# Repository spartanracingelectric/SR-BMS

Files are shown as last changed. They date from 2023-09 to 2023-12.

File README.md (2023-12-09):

# Spartan Racing BMS R&D Repository
A senior project with a goal to produce an in-house BMS using the LTC6813 to support a 600V pack, as well as analysis software to view cell data and configure the BMS.<br/>
<br/>

## Project Demonstration
YouTube Video of Project Demo (https://www.youtube.com/watch?v=ieQdnhzClfs)

## Project Folder Structure
- `altium/` : Altium Designer project files for the custom BMS master and slave PCB (schematic & layout)
- `doc/` : Supplementary documentation, mostly hardware-related (like datasheets)
- `examples/` : Firmware examples for the BMS master, various programs.
	- The primary example that was utilized was `stm32f105_isospi`
- `gui/` : GUI Analysis Software for the host computer , to visualize battery cell data and communicate with the BMS master PCBA.
- `media/` : Various photos and such

## Environment Setup
### Version Control
1. Install git ([Windows](https://git-scm.com/downloads))
2. Clone this repo into any reachable folder using, in a command line of your choice (WSL Ubuntu, PowerShell, Terminal, etc), `git clone https://github.com/spartanracingelectric/SR-BMS.git`
    1. Change your branch if necessary by using `git checkout <BRANCH_NAME>`

### Altium Designer PCB Design Setup
Simple, just open either the master or slave `.PrjPcb` files in Altium!

### Firmware Setup
1. Install STM32CubeIDE and STM32CubeProgrammer.
2. In STM32CubeIDE, import the projects from `examples/`.
3. In STM32CubeIDE, click the "build" hammer on the toolbar to compile/build one of the programs in `examples/`.
4. In STM32CubeProgrammer, flash the `.elf` binary generated in the specific example project's `Debug/` to the BMS master PCBA over ST-Link or USB.
5. Note: STM32CubeMX to make any initialization-level configuration changes for the microcontroller.

### GUI Setup
1. cd gui/bms_app
	- install necessary react scripts using 'npm install react-scripts' 
2. Backend and frontend must be run concurrently 
	- frontend: open terminal in bms_app folder use: 'npm start' 
	- backend: open terminal in serialcomm folder 'npm run dev' 
	- backend deals w/ serial communication. Ensure that the correct COM port is defined in server.js!
	- to view the backend use the url: "http://localhost:8000/graphdata" 
<br/>

## SR BMS R&D Senior Project Team
_Vincent Saw_, Ex-Software Lead for Spartan Racing, Firmware & Hardware & Integration<br/>
_Vincent Pham_, Project Member, Firmware & Hardware<br/>
_Josh Samoy_, Project Member, Firmware & Software<br/>
_Abegail Palad_, Project Member, Firmware & Software<br/>
<br/>

## Links
[Primary Repo for BMS Senior Project](https://github.com/spartanracingelectric/SR-BMS)<br/>
[Old GUI Analysis Software Repo](https://github.com/Sensei-Josh/Senior_project_GUI)<br/>
[Spartan Racing Website](https://www.sjsuformulasae.com/)<br/>

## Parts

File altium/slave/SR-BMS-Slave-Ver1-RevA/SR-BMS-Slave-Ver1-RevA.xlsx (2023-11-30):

Line # | Name | Description | Designator | Quantity | Manufacturer 1 | Manufacturer Part Number 1 | Manufacturer Lifecycle 1 | Supplier 1 | Supplier Part Number 1 | Supplier Unit Price 1 | Supplier Subtotal 1
 | 885382207009 | Multilayer Ceramic Chip Capacitor WCAP-CSST Series 0805 10000pF X7R0805103K100DFCT1S000 | C0, C1, C2, C3, C4, C5, C6, C7, C8, C9, C10, C11, C12, C13, C14, C15, C16, C17, C18, C19, C20, C21, C22, C23, C25, C26, C27, C28, C29, C30, C31, C32, C33, C34, C35, C36, C53, C54, C55, C56 | 40
 | Capacitor | Capacitor | C37, C38, C39, C40, C41, C42, C43, C44, C45, C46, C47 | 11
 | Capacitor | Capacitor | C48, C49, C50, C51, C52 | 5
 | MFU0603FF00500P500 | Fuse | F1, F2, F3, F4, F5, F6, F7, F8, F9, F10, F11, F12, F13, F14, F15, F16, F17, F18 | 18
 | BLM18PG330SN1D | Ferrite Bead | FB1 | 1
 | 15-91-2025 | CONN HEADER SMD R/A 2POS 2.54MM | J1, J2 | 2 | Molex | 15-91-2025 | Volume Production | Farnell | 3862877 | 3.08 | 6.16
 | 70553-0044 | Connector | J3 | 1
 | 70555-0018 | Connector | J4 | 1
 | LS_L29K-G1H2-1 | LED | LED1, LED2, LED3, LED4, LED5, LED6, LED7, LED8, LED9, LED10, LED11, LED12, LED13, LED14, LED15, LED16, LED17, LED18 | 18
 | BSS308PE | P-Channel OptiMOS P3 Small-Signal-Transistor, -30 V VDS, -2 A ID, -55 to 150 degC, PG-SOT23, Reel, Green | Q1, Q2, Q3, Q4, Q5, Q6, Q7, Q8, Q9, Q10, Q11, Q12, Q13, Q14, Q15, Q16, Q17, Q18 | 18 | Infineon | BSS308PE | Volume Production | Digi-Key | BSS308PEH6327XTSA1CT-ND | 0.358 | 6.44
 | NSV1C201MZ4T1G | Transistor | Q19 | 1
 | Resistor | Resistor | R1, R2, R3, R4, R5, R6, R7, R8, R9, R10, R12, R13, R14, R15, R16, R17, R18, R19, R20, R26, R27, R28, R29, R30, R31, R32, R33, R34, R36, R37, R38, R39, R43, R44, R45, R47, R48, R50, R51, R52, R53, R54, R58, R59, R60, R61, R62, R63, R66, R67, R68, R69, R70, R71 | 54
 | Resistor | Resistor | R11, R21, R22, R23, R24, R25, R35, R40, R41, R42, R46, R55, R56, R57, R64, R65, R72, R73 | 18
 | Resistor | Resistor | R49, R74 | 2
 | Resistor | Resistor | R75, R76, R77, R78, R79, R80, R81, R82, R83 | 9
 | Resistor | Resistor | R84, R87, R88, R89, R90, R91 | 6
 | Resistor | Resistor | R85 | 1
 | Resistor | Resistor | R86 | 1
 | Resistor | Resistor | R92 | 1
 | Resistor | Resistor | R94, R95, R96, R97 | 4
 | SM91502ALE | BMS XFORMER 1-CH 1000V AECQ +125 | T1, T2 | 2 | Bourns | SM91502ALE | Volume Production | Newark | 95AC3538 | 2.81 | 5.62
 | LTC6813HLWE-1#3ZZPBF | 18 CHANNEL MULTICELL BATTERY STA | U1 | 1 | Analog Devices / Linear Technology | LTC6813HLWE-1#3ZZPBF | Unknown
 | PDZ7.5B,115 | Zener Diode | Z1, Z2, Z3, Z4, Z5, Z6, Z7, Z8, Z9, Z10, Z11, Z12, Z13, Z14, Z15, Z16, Z17, Z18 | 18

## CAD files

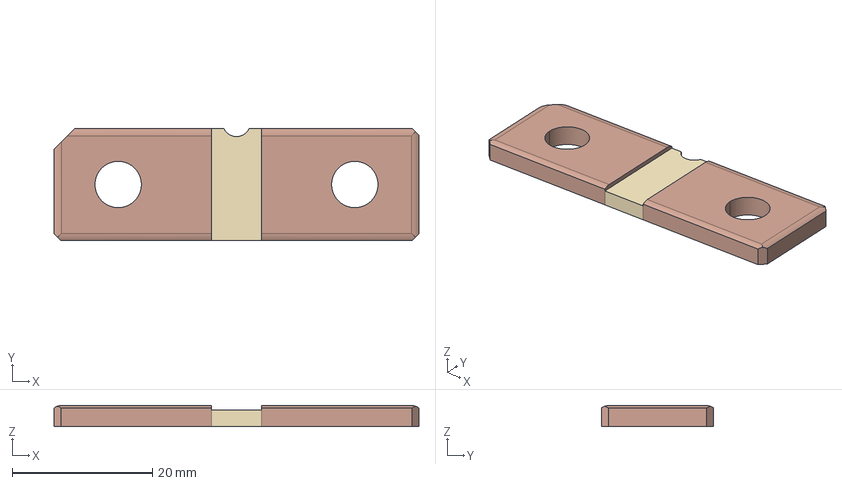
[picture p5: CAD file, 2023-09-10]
altium/master/stm32f105/SR-BMS-Master-Ver1-RevB_stm32f105/WSBS5216L1000KK.stp
52.0 x 16.0 x 3.00 mm

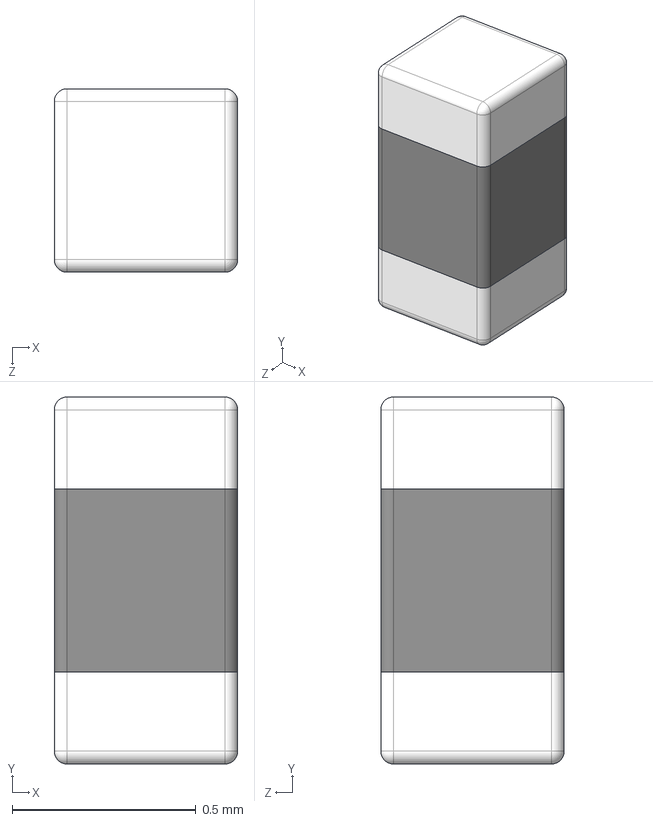
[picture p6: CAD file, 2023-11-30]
altium/slave/SR-BMS-Slave-Ver1-RevA/dependencies/LIB_BLM15PX600BH1D/BLM15PX600BH1D/3D/BLM15PX600BH1D.stp
0.5 x 1.00 x 0.5 mm

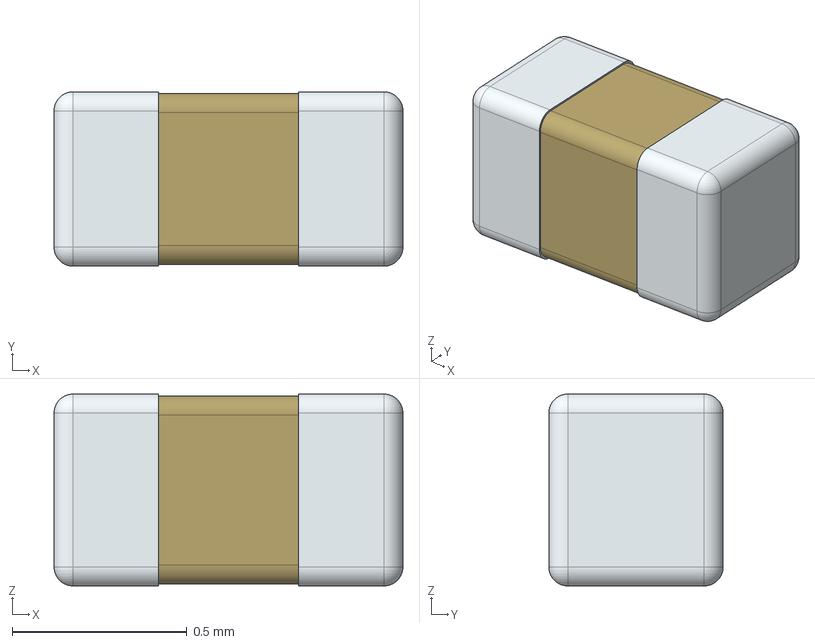
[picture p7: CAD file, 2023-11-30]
altium/slave/SR-BMS-Slave-Ver1-RevA/dependencies/LIB_C0402C103K1RACAUTO/C0402C103K1RACAUTO/3D/C0402C103K1RACAUTO.stp
1.00 x 0.5 x 0.55 mm

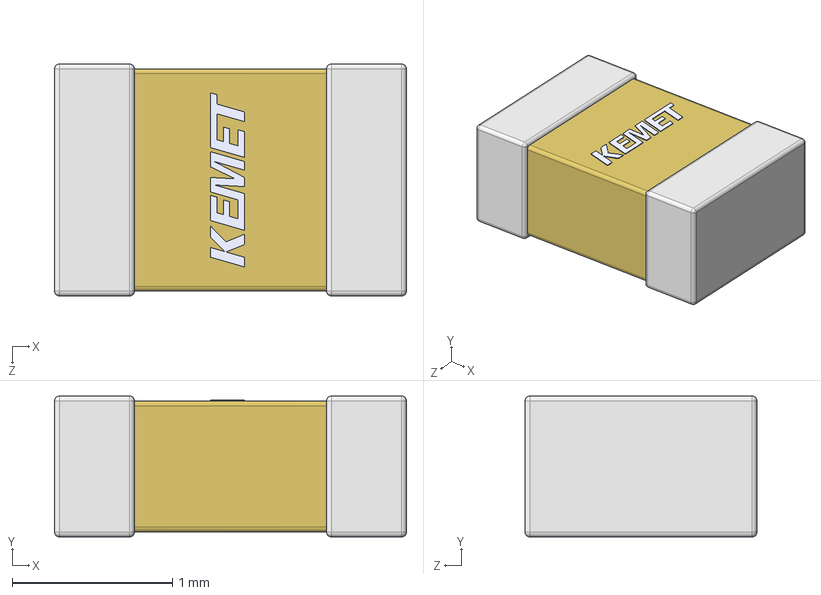
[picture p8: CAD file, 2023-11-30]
altium/slave/SR-BMS-Slave-Ver1-RevA/dependencies/LIB_C0805C109B3GACTU/C0805C109B3GACTU/3D/C0805C109B3GACTU.stp
2.20 x 0.88 x 1.45 mm

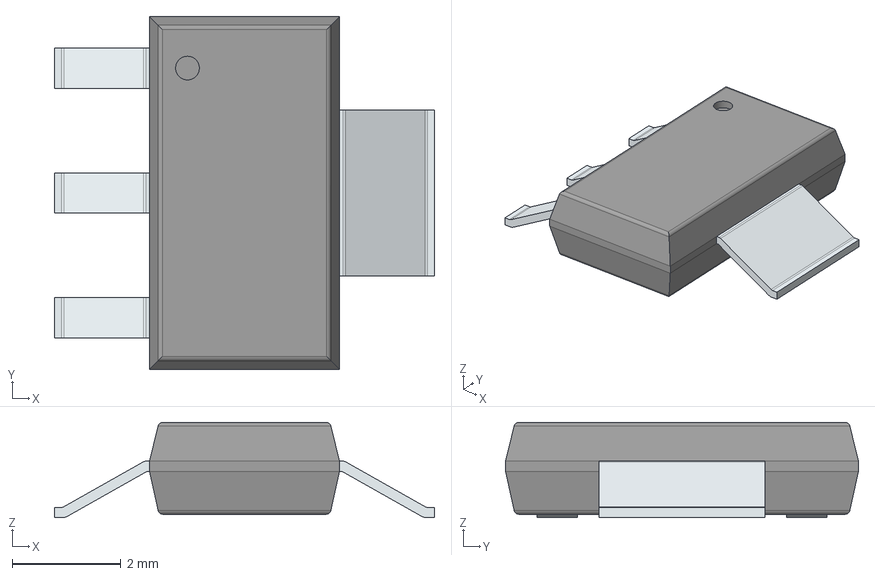
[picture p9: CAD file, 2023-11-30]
altium/slave/SR-BMS-Slave-Ver1-RevA/dependencies/LIB_NSV1C201MZ4T1G/NSV1C201MZ4T1G/3D/NSV1C201MZ4T1G.stp
7.00 x 6.50 x 1.75 mm
PinsArrayL
FilletPinR

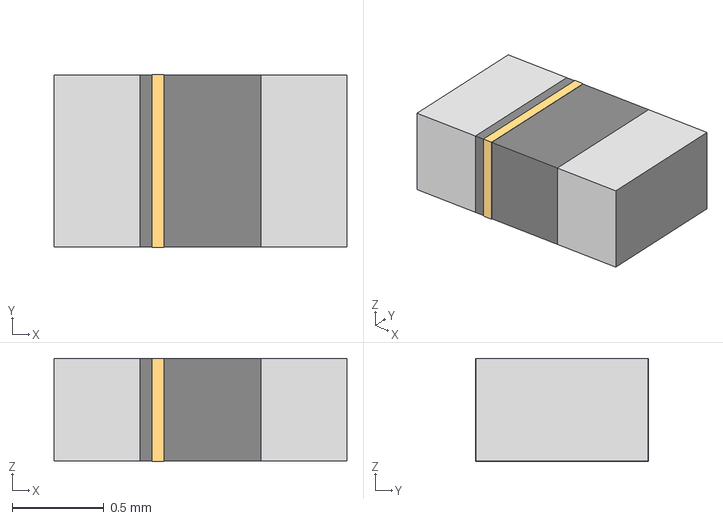
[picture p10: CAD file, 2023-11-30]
altium/slave/SR-BMS-Slave-Ver1-RevA/dependencies/ul_MFU0603FF00500P500/AltiumDesigner/FUS_VISHAY_MFU0603_VIS.step
1.60 x 0.944 x 0.564 mm

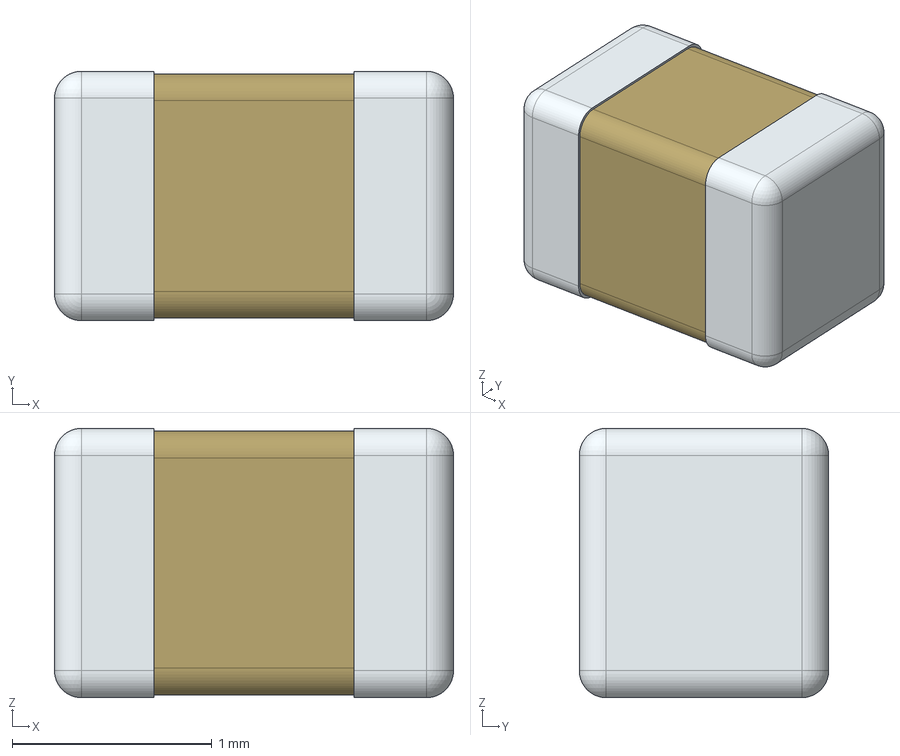
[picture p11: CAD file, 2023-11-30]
altium/slave/SR-BMS-Slave-Ver1-RevA/dependencies/LIB_885382207009/885382207009/3D/885382207009.stp
2.00 x 1.25 x 1.35 mm

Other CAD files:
altium/slave/SR-BMS-Slave-Ver1-RevA/dependencies/LIB_885382207009/885382207009/Allegro/capc2012x135n.psm
altium/slave/SR-BMS-Slave-Ver1-RevA/dependencies/LIB_885382207009/885382207009/DEHDL/885382207009/chips/chips.prt
altium/slave/SR-BMS-Slave-Ver1-RevA/dependencies/LIB_BLM15PX600BH1D/BLM15PX600BH1D/Allegro/nfz15sg152sn10b.psm
altium/slave/SR-BMS-Slave-Ver1-RevA/dependencies/LIB_BLM15PX600BH1D/BLM15PX600BH1D/DEHDL/blm15px600bh1d/chips/chips.prt
altium/slave/SR-BMS-Slave-Ver1-RevA/dependencies/LIB_C0402C103K1RACAUTO/C0402C103K1RACAUTO/Allegro/capc1005x55n.psm
altium/slave/SR-BMS-Slave-Ver1-RevA/dependencies/LIB_C0402C103K1RACAUTO/C0402C103K1RACAUTO/DEHDL/c0402c103k1racauto/chips/chips.prt
altium/slave/SR-BMS-Slave-Ver1-RevA/dependencies/LIB_C0805C109B3GACTU/C0805C109B3GACTU/Allegro/c0805.psm
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

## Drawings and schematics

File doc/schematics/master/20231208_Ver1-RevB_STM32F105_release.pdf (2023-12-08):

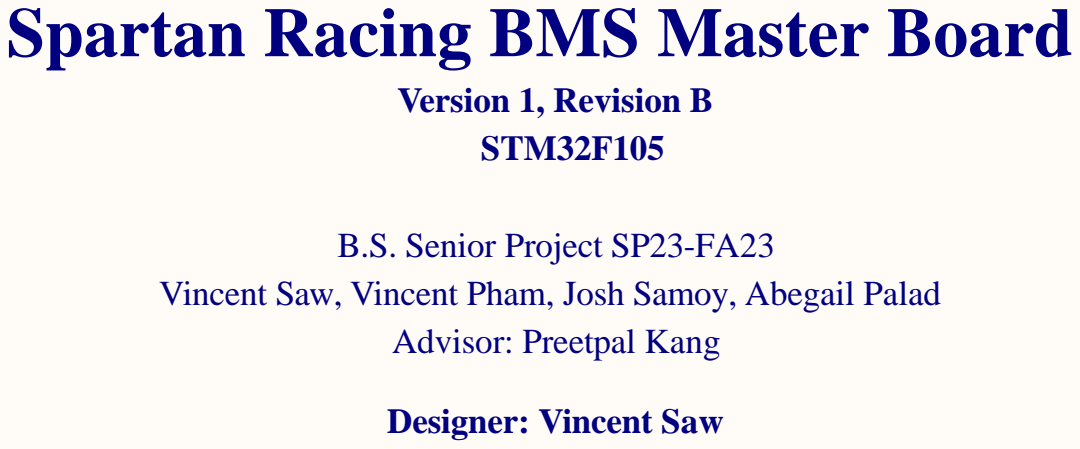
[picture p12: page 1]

Spartan Racing BMS Master Board

Vincent Saw, Vincent Pham, Josh Samoy, Abegail Palad

Title
BMS Master Cover Sheet

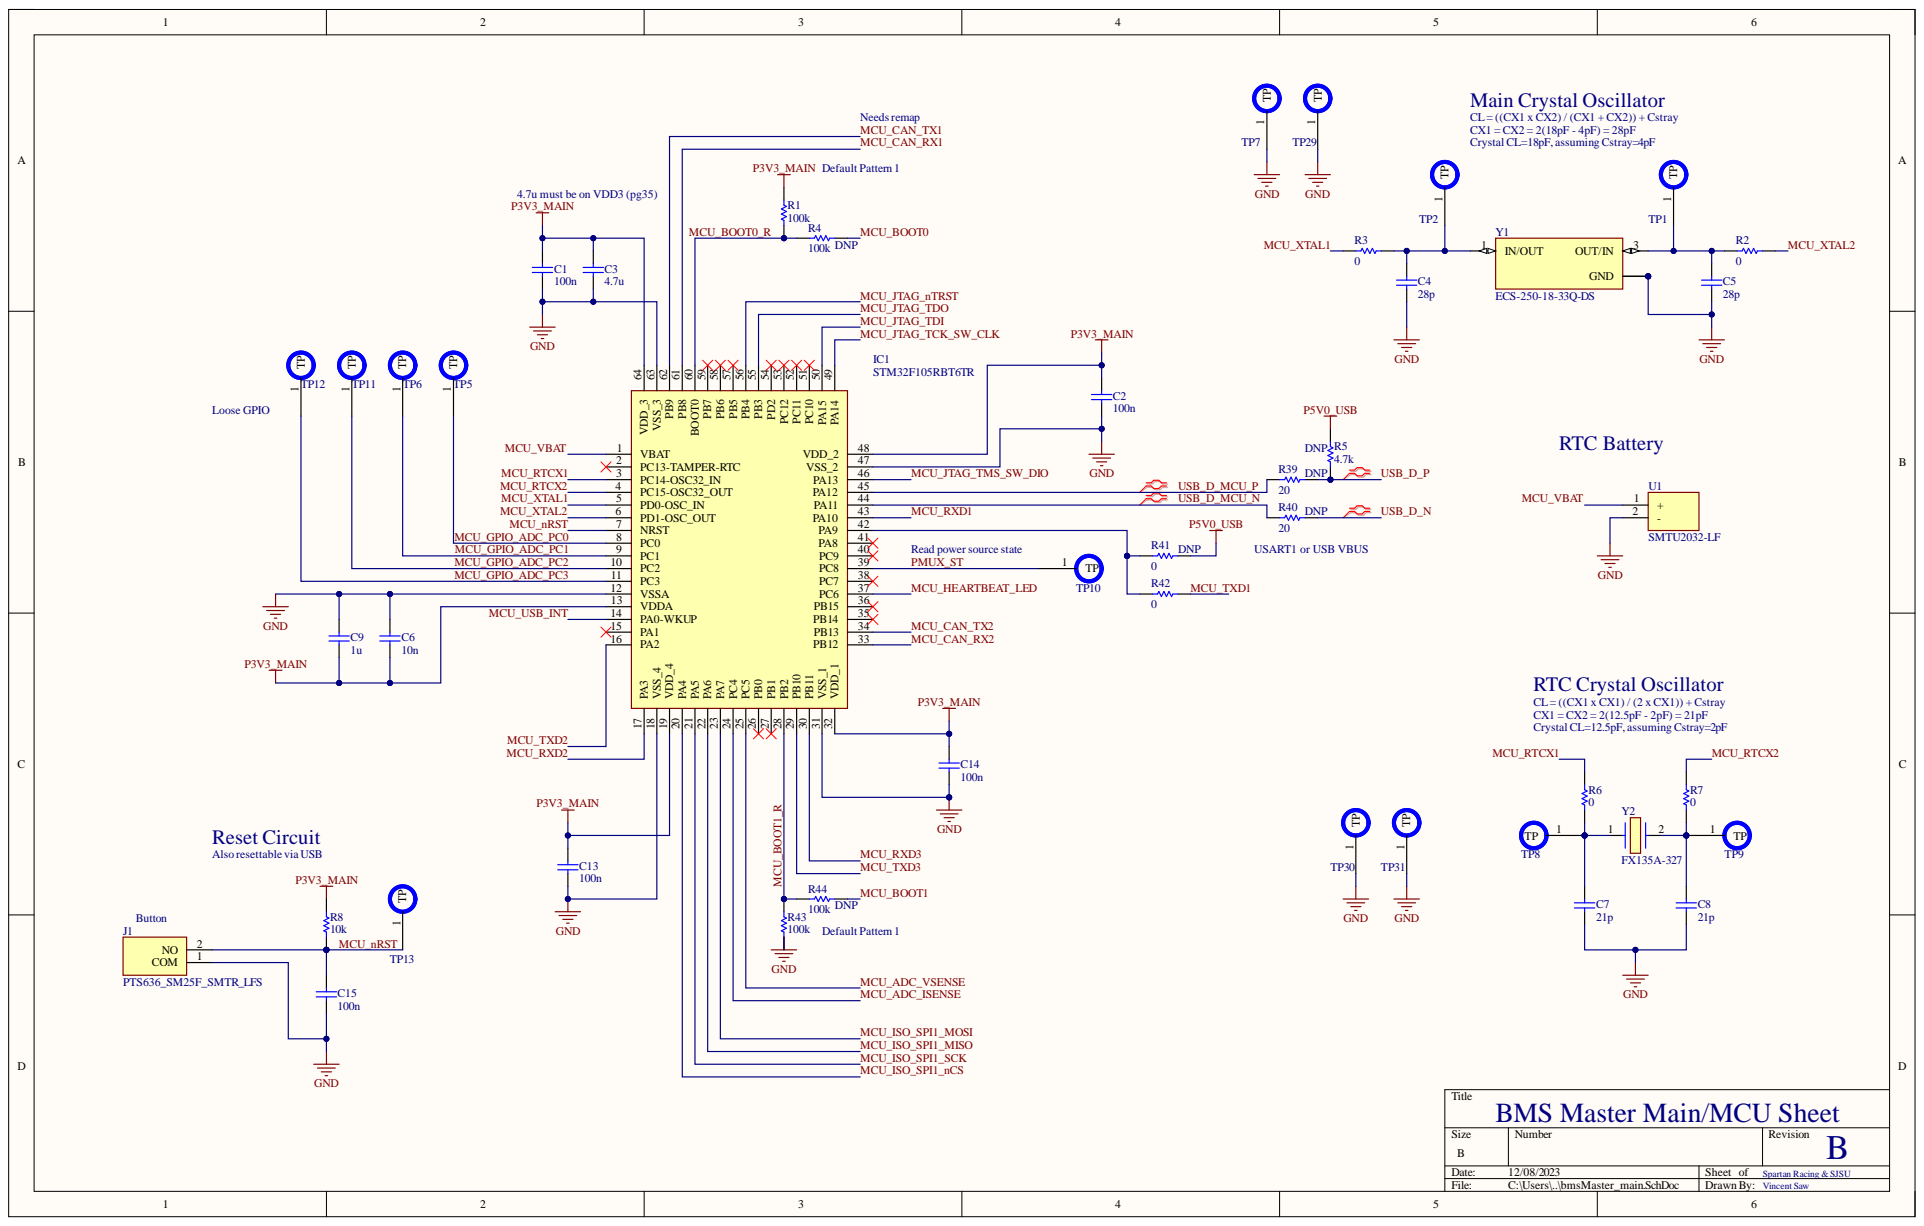
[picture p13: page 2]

Main Crystal Oscillator

PC14-OSC32_IN 3 | MCU_JTAG_TMS_SW_DIO GND
PC15-OSC32_OUT 4 | | USB_D_MCU_P
PD0-OSC_IN 5 | USB_D_MCU_N | + 1

RTC Crystal Oscillator CL= ((CX1 x CX1) / (2 x CX1)) + Cstray

Reset Circuit
Also resettable via USB

Title
BMS Master Main/MCU Sheet

Size B | Number | Revision B

Date: 12/08/2023 | Sheet of Spartan Racing & SJSU
File: C:\Users\..\bmsMaster_main.SchDoc | Drawn By: Vincent Saw

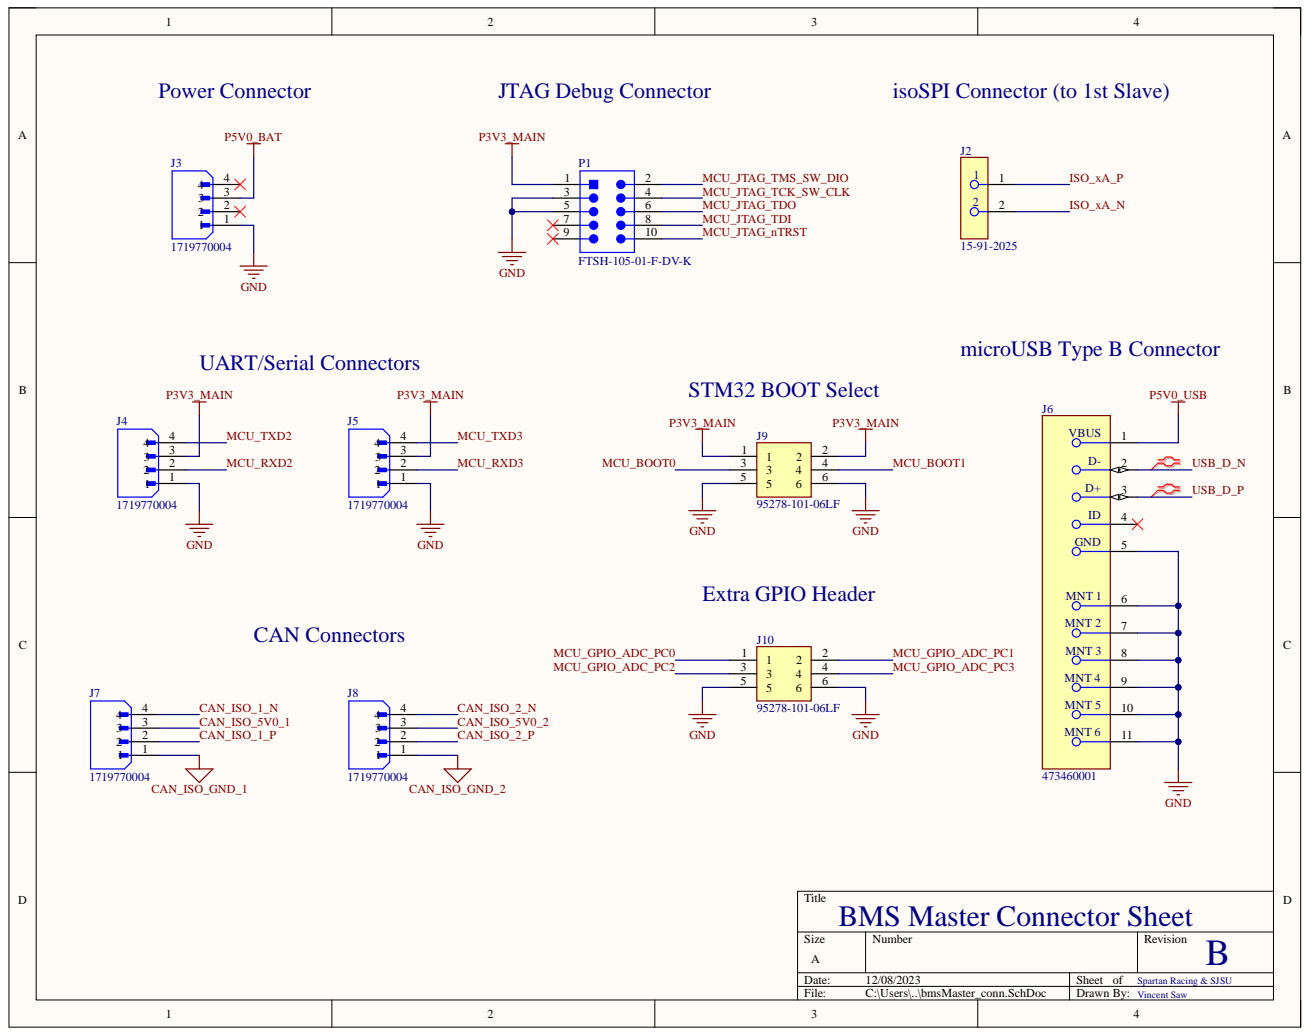
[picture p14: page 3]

Title
BMS Master Connector Sheet

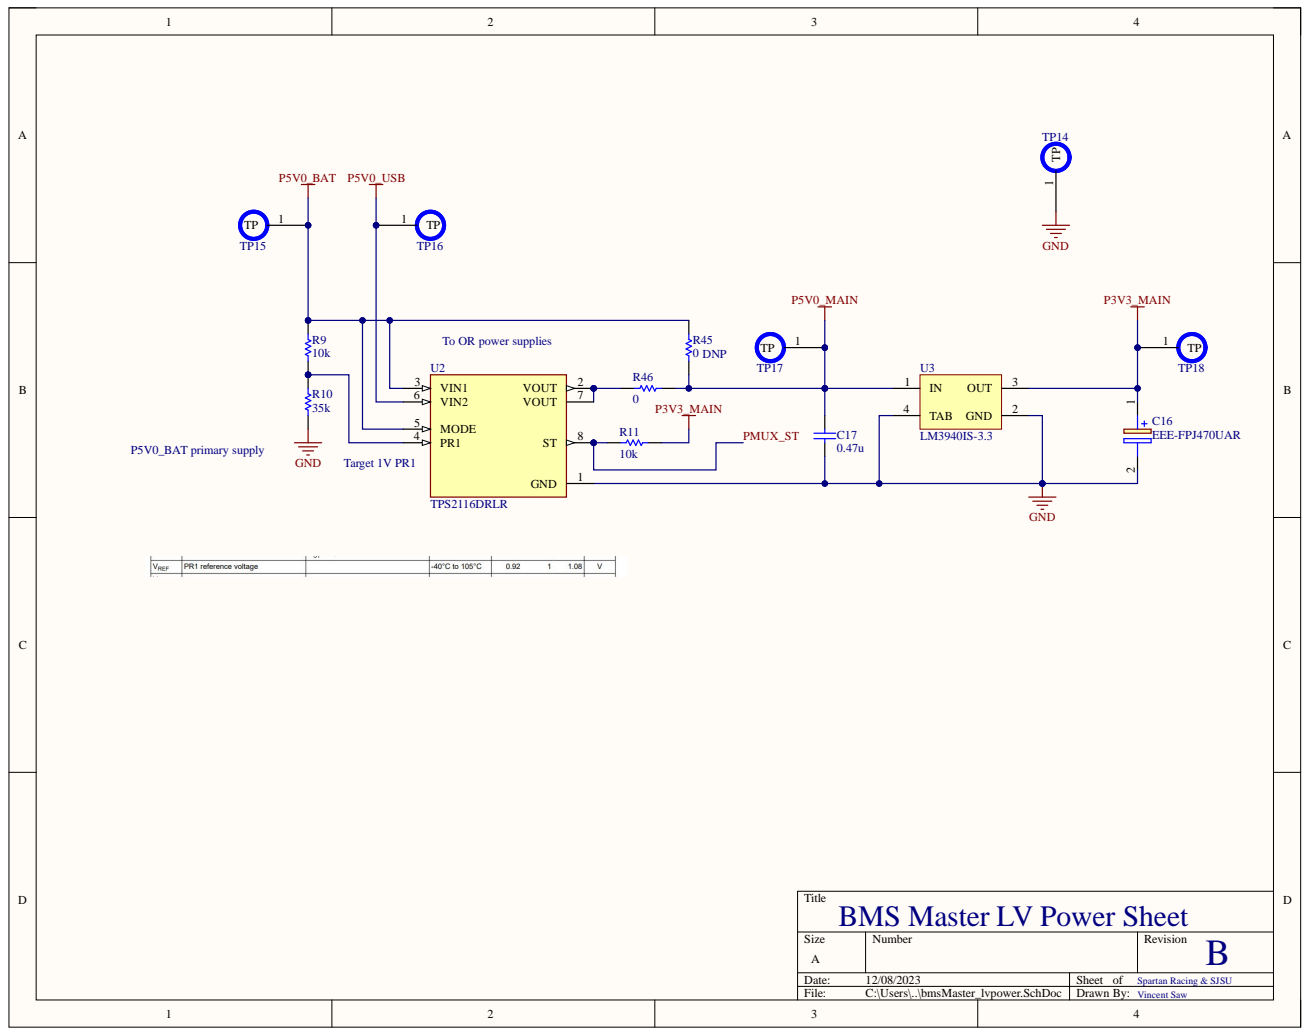
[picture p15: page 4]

To OR power supplies

Title
BMS Master LV Power Sheet

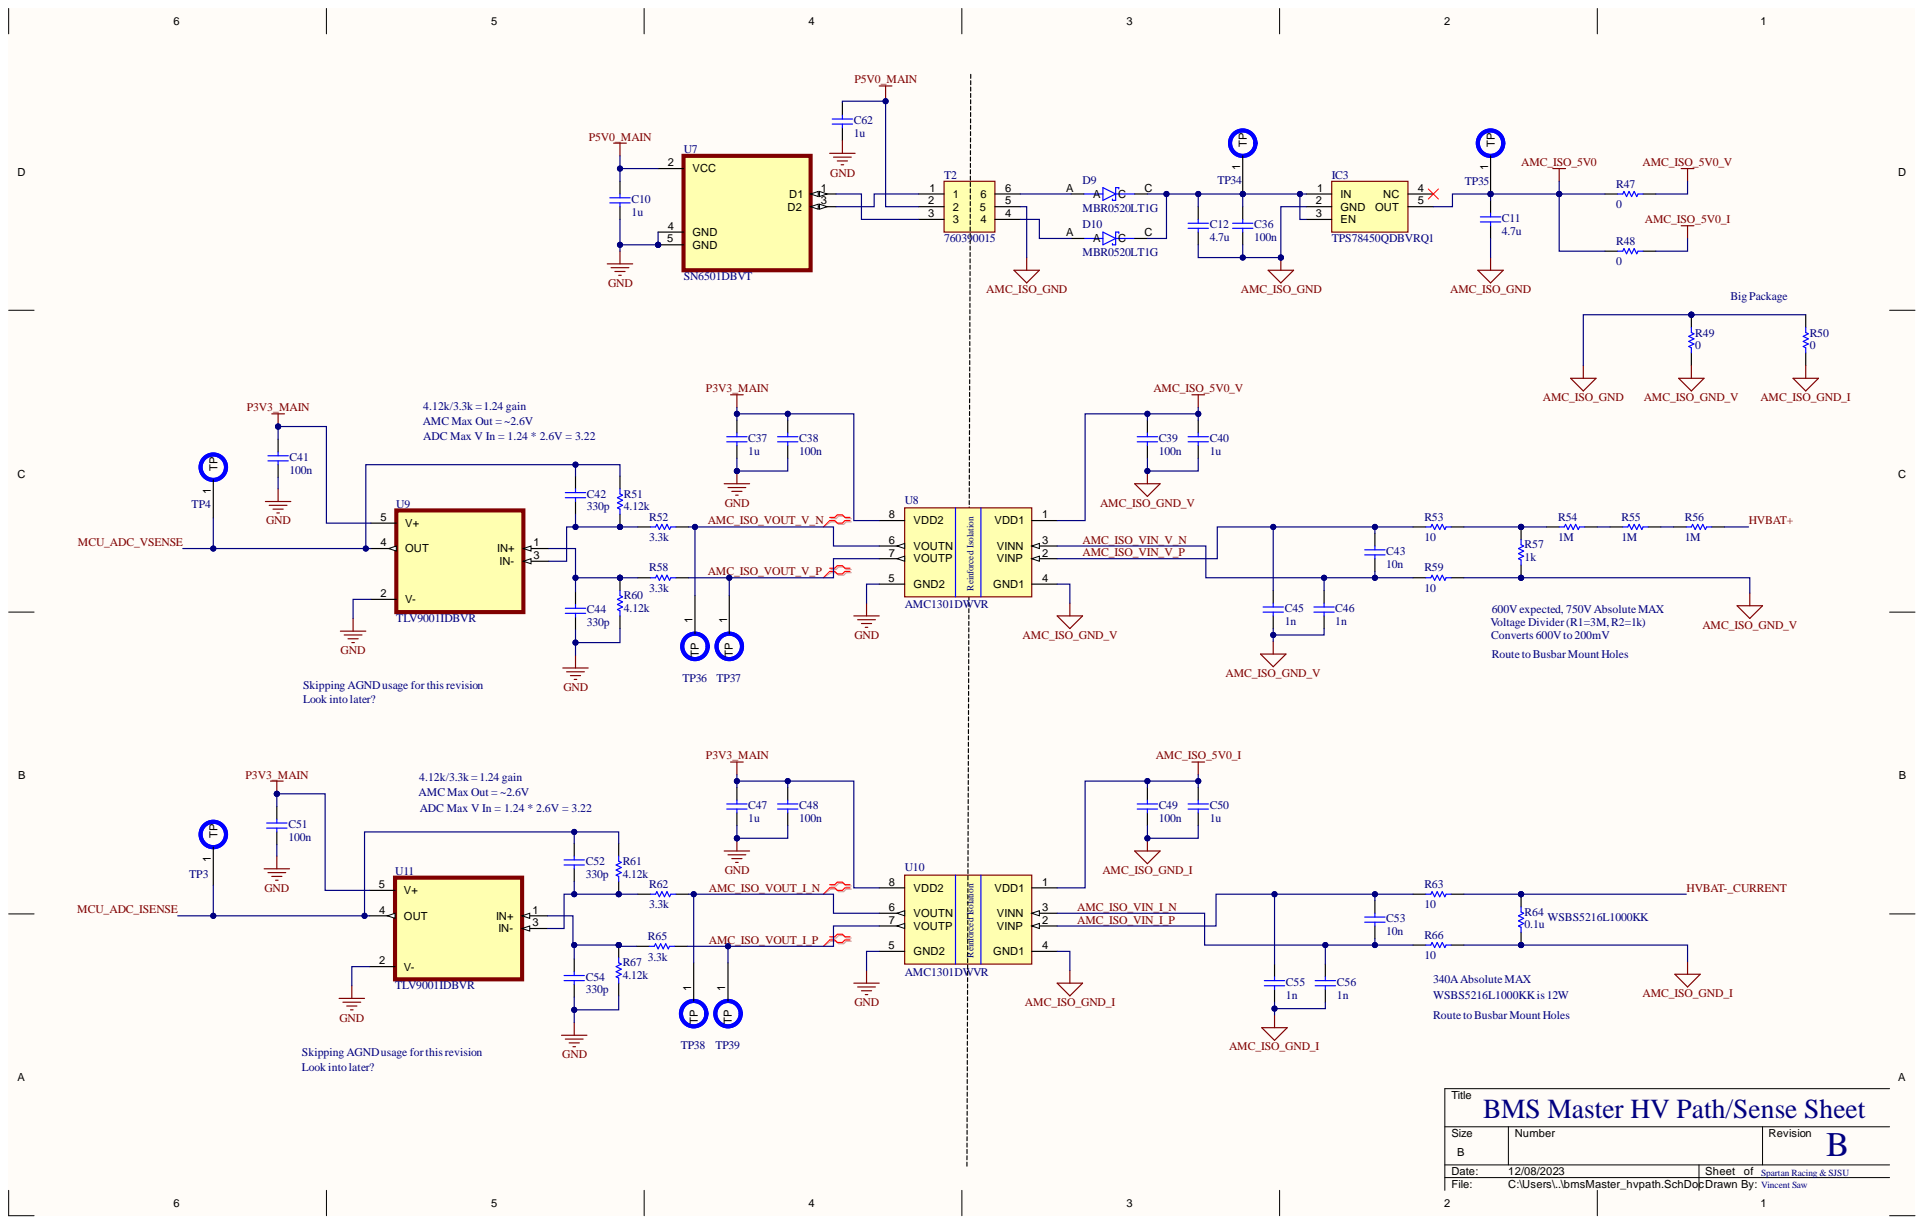
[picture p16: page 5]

600V expected, 750V Absolute MAX
Voltage Divider(R1=3M, R2=1k)
Converts 600V to 200mV
Route to Busbar Mount Holes

WSBS5216L1000KKis 12W

Title
BMS Master HV Path/Sense Sheet

Size B | Number | Revision B

Date: 12/08/2023 | Sheet of Spartan Racing & SJSU
File: C:\Users\..\bmsMaster_hvpath.SchDocDrawn By: | Vincent Saw

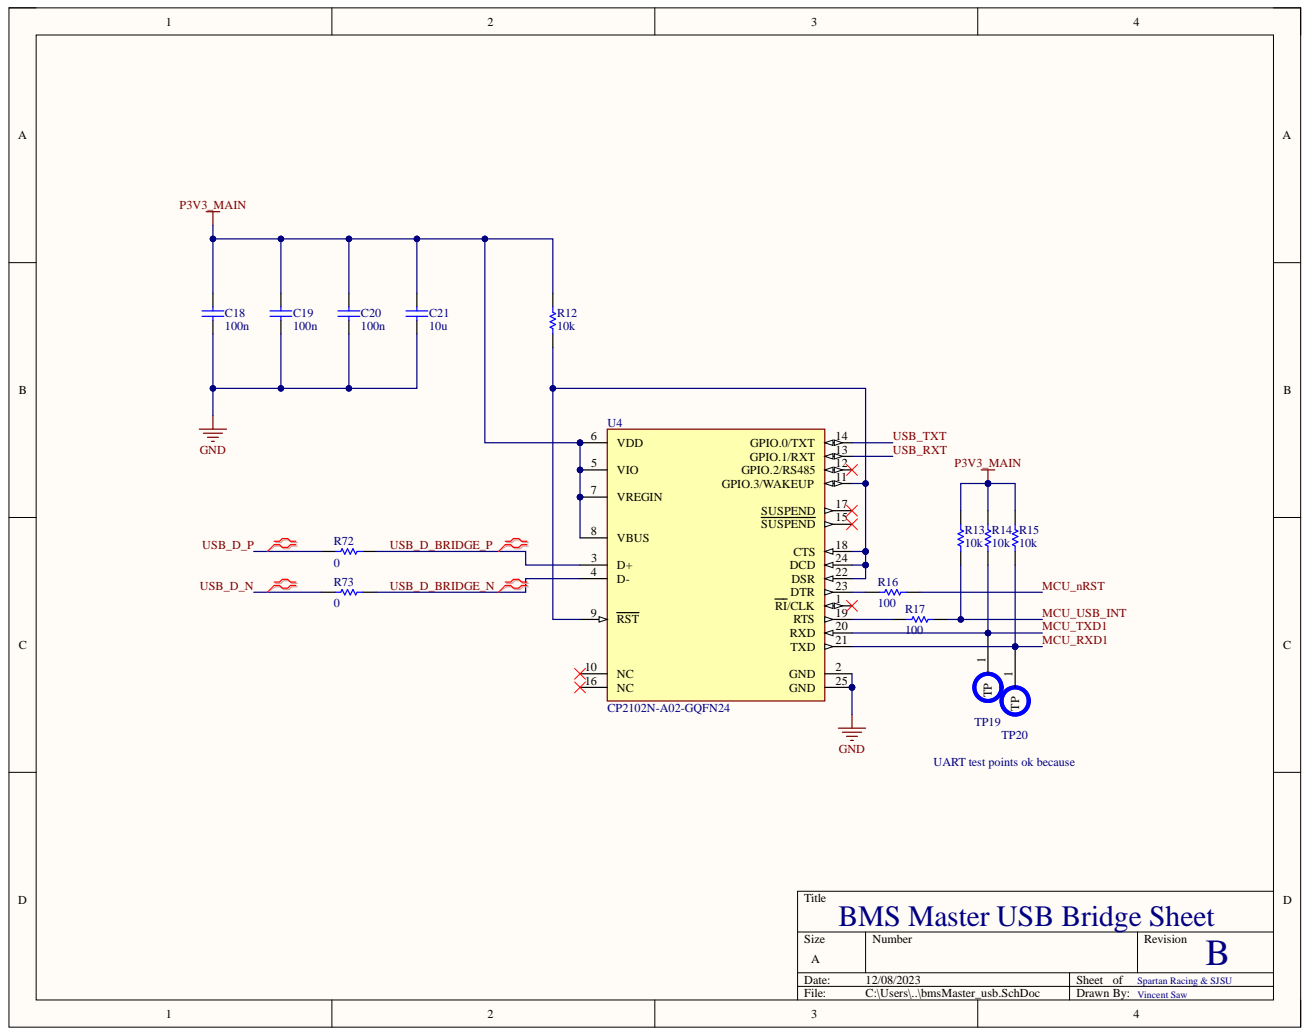
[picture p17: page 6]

UART test points ok because

Title
BMS Master USB Bridge Sheet

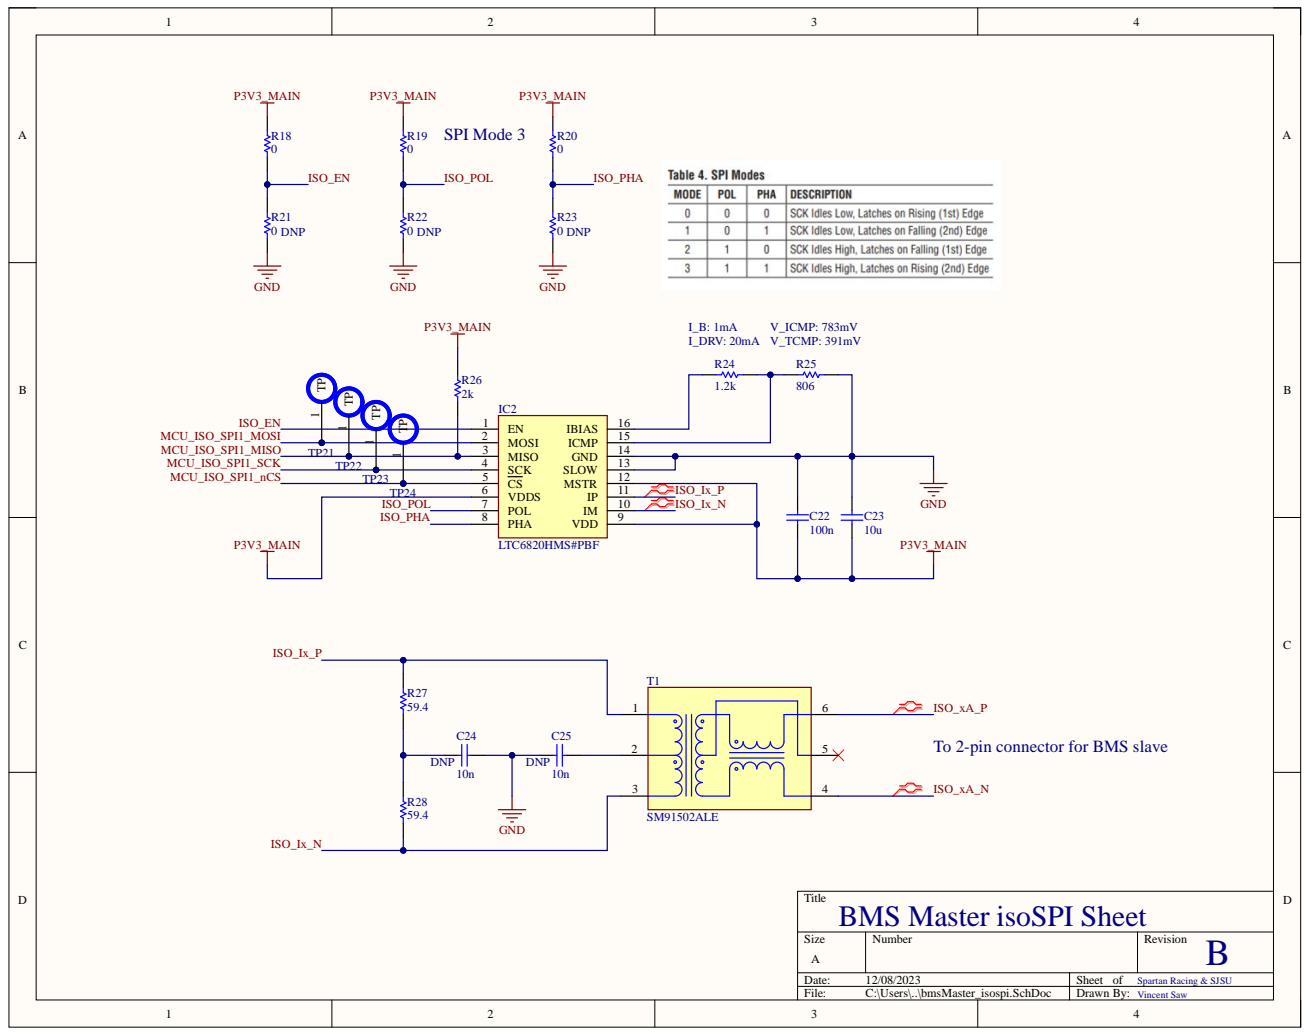
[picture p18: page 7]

To 2-pin connector for BMS slave

Title
BMS Master isoSPI Sheet

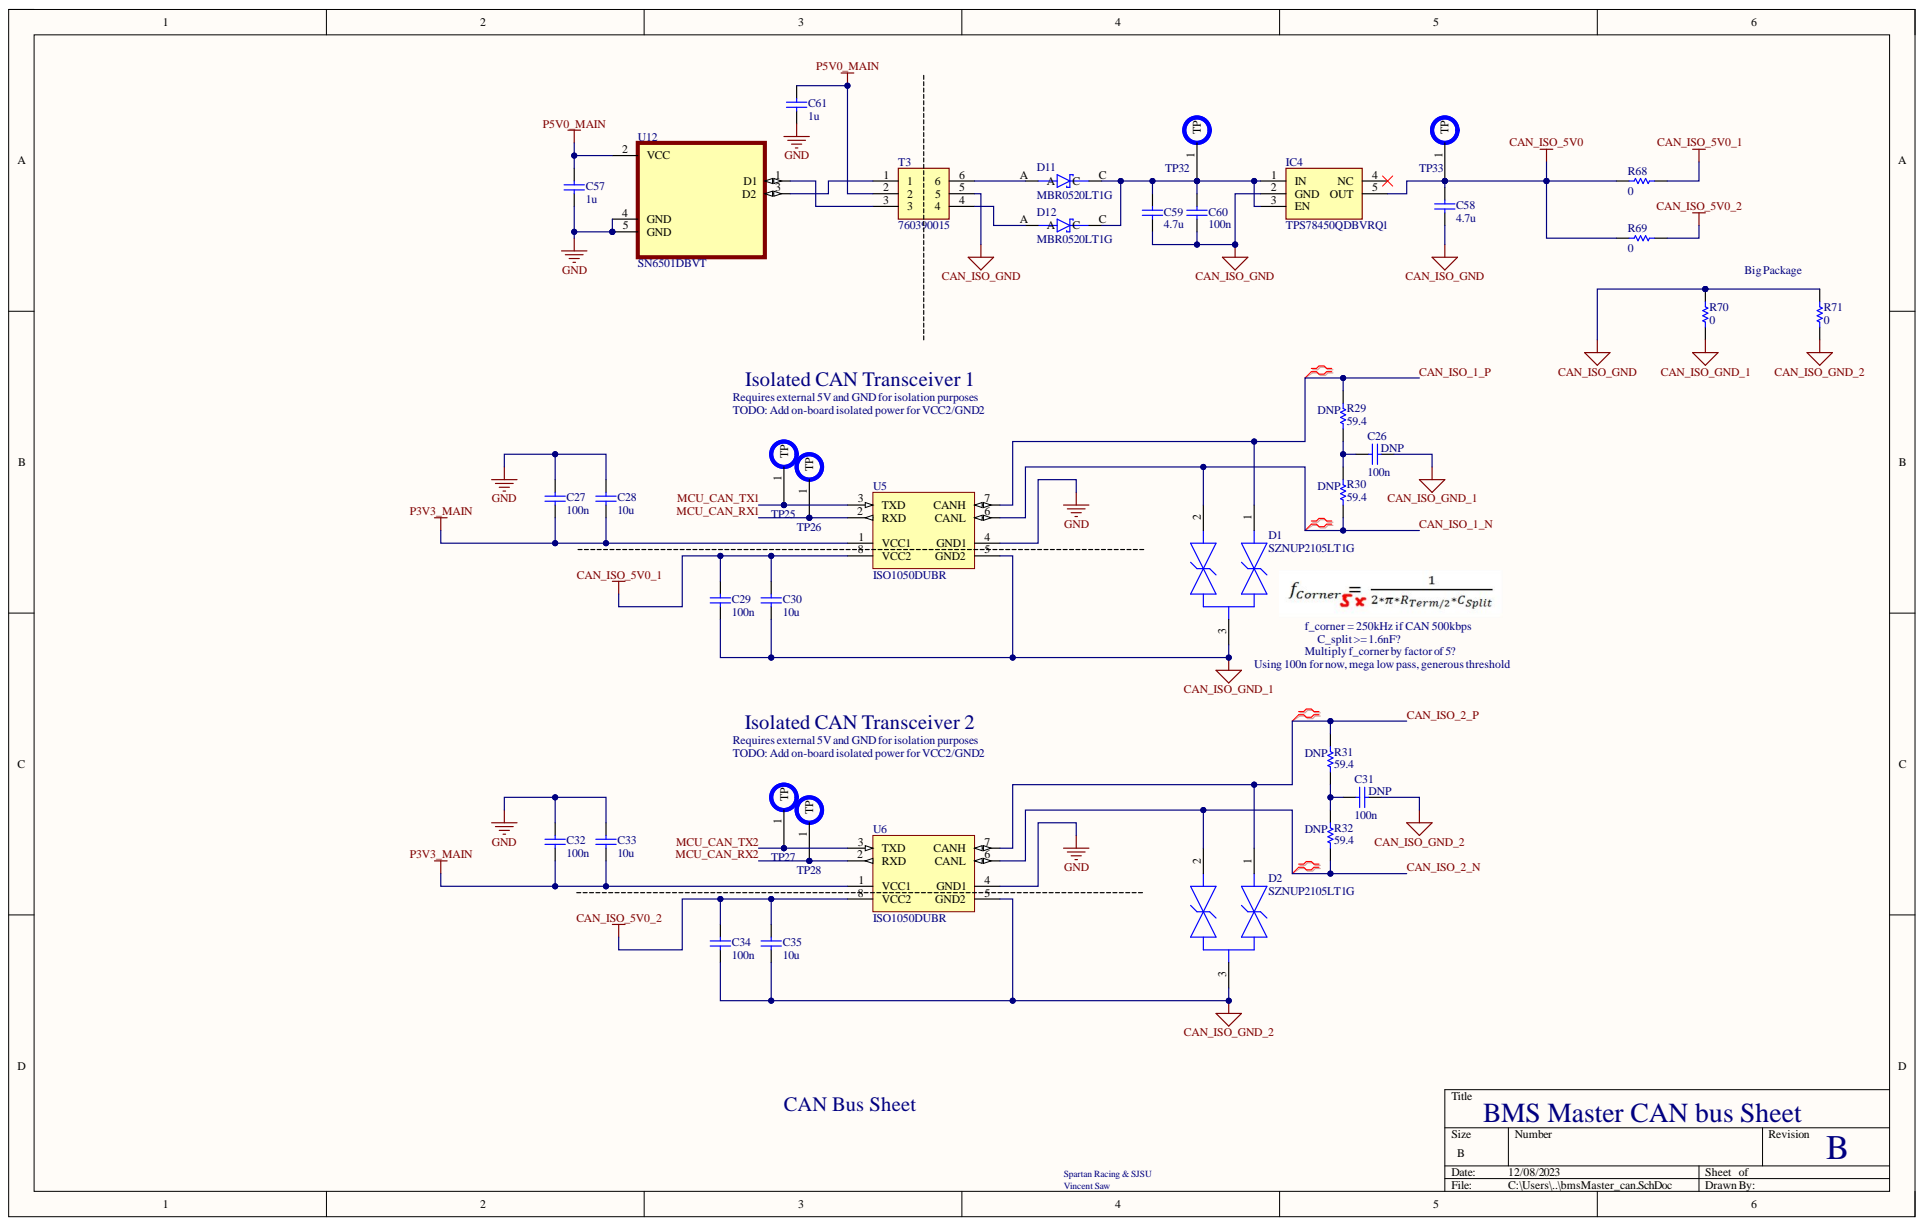
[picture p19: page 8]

Si z e | Num b er | Revi s i on B

e : 12/08/ 20 2 3 | Sheet of
Fi l e : C : \U ser s \..\bm s Mas ter_can . S chDo c | D rawn By:

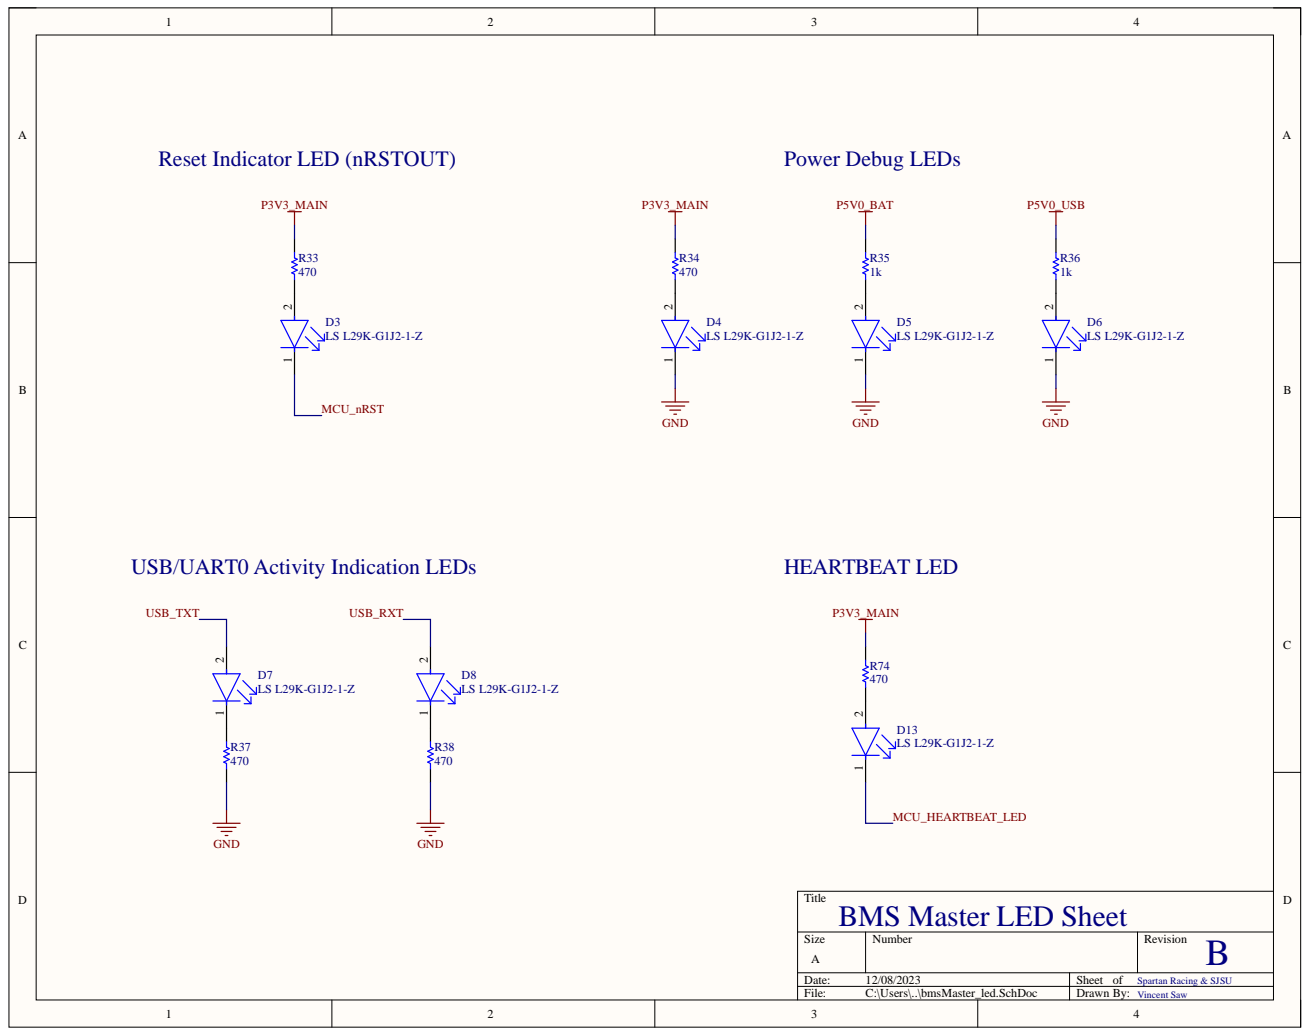
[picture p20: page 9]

USB/UART0 Activity Indication LEDs

Title
BMS Master LED Sheet

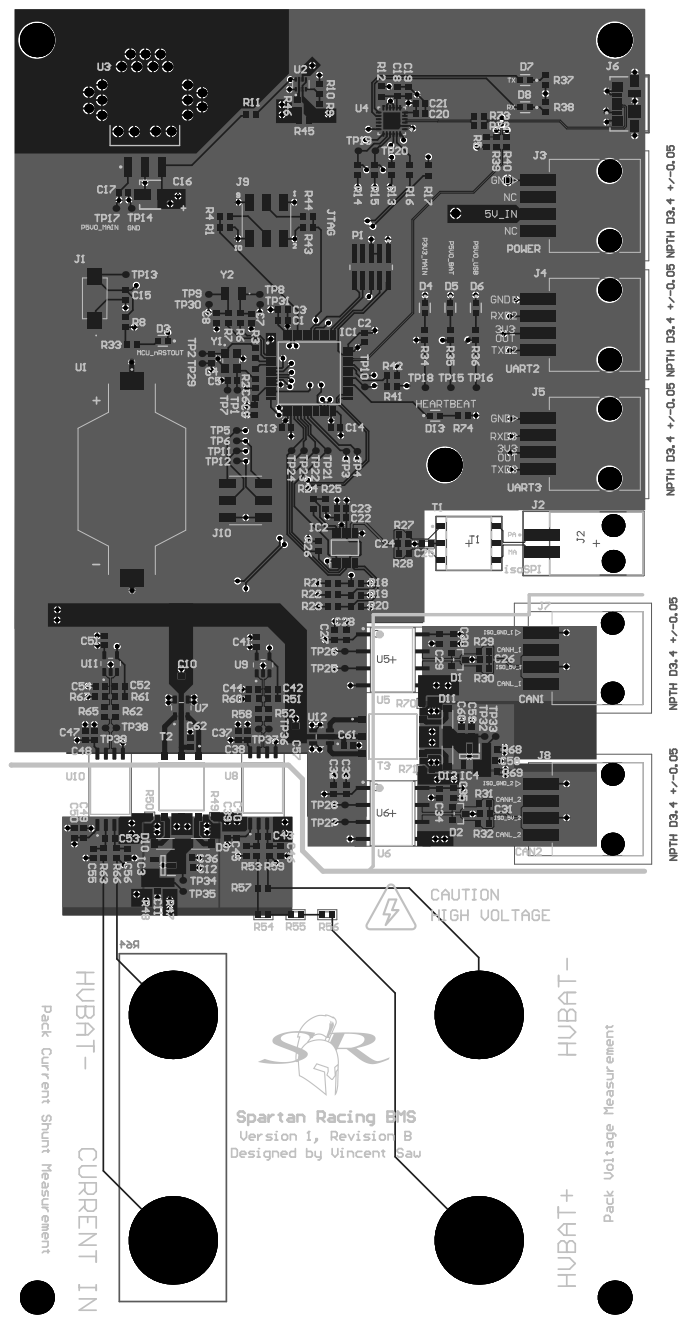
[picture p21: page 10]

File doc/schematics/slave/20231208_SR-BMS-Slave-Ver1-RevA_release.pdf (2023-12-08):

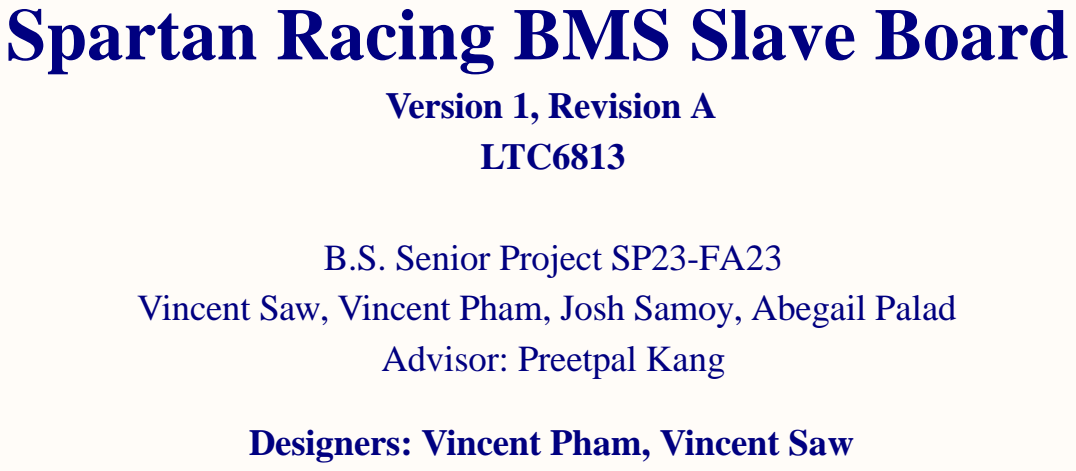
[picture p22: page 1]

Spartan Racing BMS Slave Board

Vincent Saw, Vincent Pham, Josh Samoy, Abegail Palad

Designers: Vincent Pham, Vincent Saw

Title
BMS Slave Cover Sheet

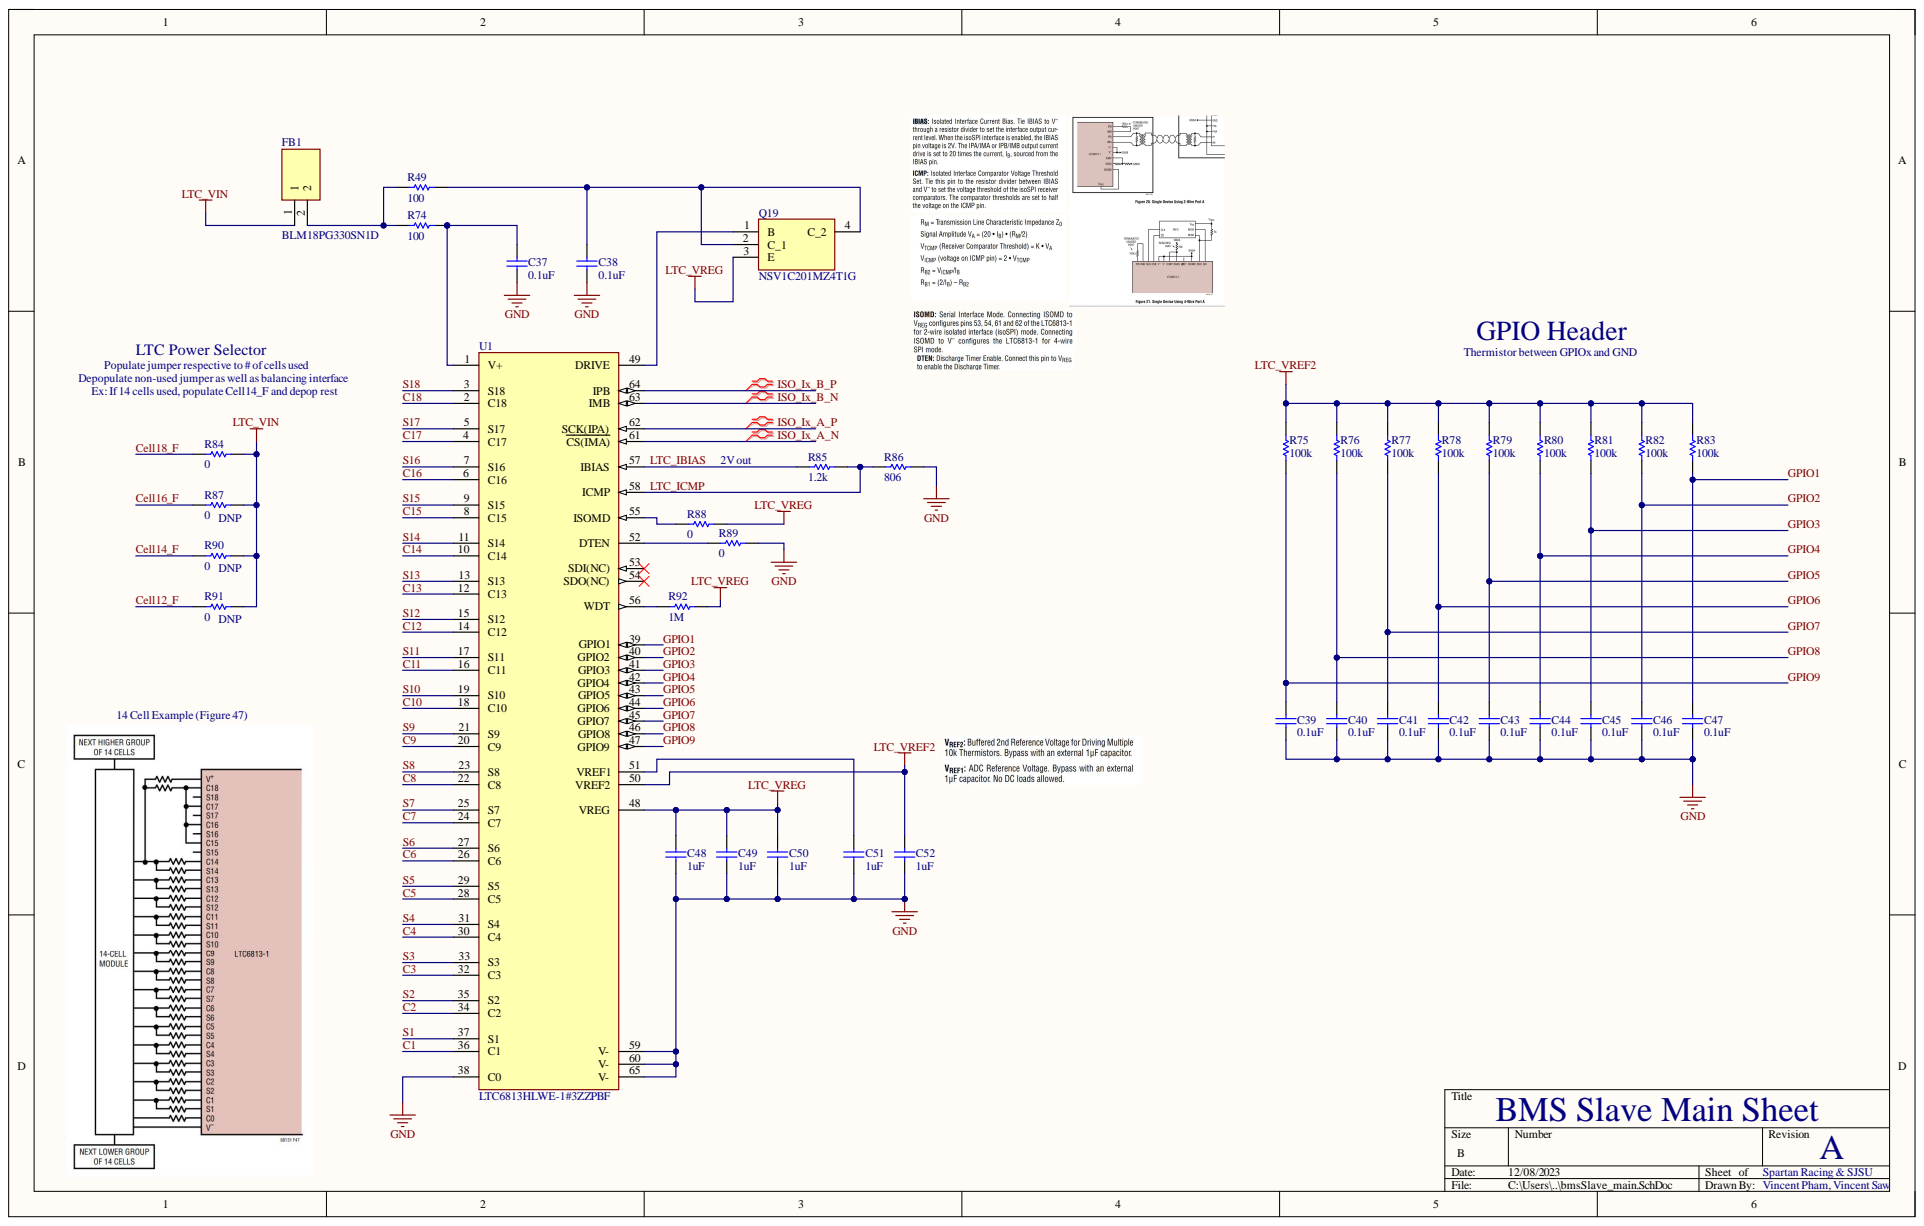
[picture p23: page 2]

r Populate jumperrespective to # of cel

BMS Slave Main Sheet

e : 12/08/ 20 2 3 | Sheet of Spar tan Racing & SJSU
Fi l e : C : \U ser s \..\bm sSlave_mai n . S chDo c | D rawn By: Vincent Pham, Vincent S aw


BMS Slave Connector Sheet Spartan Racing & SJSU Vincent Pham, Vincent Saw A


BMS Slave Cell Intf. Sheet

Si z e | Num b er | Revi s i on A

e : 12/08/ 20 2 3 | Sheet of Spar tan Racing & SJSU
Fi l e : C : \U ser s \..\bm sSlave_cel l s . S chDo c | D rawn By: Vincent Pham, Vincent S aw


To upstream BMS slave (or master)

To downstream BMS slave

FOLLOW DATASHEET LAYOUT GUIDELINES!

BMS Slave isoSPI Sheet Spartan Racing &


Line # | Name | Description | Designator | Quantity | Manufacturer 1 | Manufacturer Part Number 1 | Manufacturer Lifecycle 1 | Supplier 1 | Supplier Part Number 1 | Supplier Unit Price 1 | Supplier Subtotal 1
| 885382207009 | Multilayer Ceramic Chip Capacitor WCAP-CSST Series 0805 10000pF X7R0805103K100DFC T1S000 | C0, C1, C2, C3, C4, C5, C6, C7, C8, C9, C10, C11, C12, C13, C14, C15, C16, C17, C18, C19, C20, C21, C22, C23, C25, C26, C27, C28, C29, C30, C31, C32, C33, C34, C35, C36, C53, C54, C55, C56 | 40
| Capacitor | Capacitor | C37, C38, C39, C40, C41, C42, C43, C44, C45, C46, C47 | 11
| Capacitor | Capacitor | C48, C49, C50, C51, C52 | 5
| MFU0603FF00500P500 | Fuse | F1, F2, F3, F4, F5, F6, F7, F8, F9, F10, F11, F12, F13, F14, F15, F16, F17, F18 | 18
| BLM18PG330SN1D | Ferrite Bead | FB1 | 1
| 15-91-2025 | CONN HEADER SMD R/A 2POS 2.54MM | J1, J2 | 2 | Molex | 15-91-2025 | Volume Production | Farnell | 3862877 | 3.08 | 6.16
| 70553-0044 | Connector | J3 | 1
| 70555-0018 | Connector | J4 | 1
| LS_L29K-G1H2-1 | LED | LED1, LED2, LED3, LED4, LED5, LED6, LED7, LED8, LED9, LED10, LED11, LED12, LED13, LED14, LED15, LED16, LED17, LED18 | 18
| BSS308PE | P-Channel OptiMOS P3 Small-Signal-Transistor, -30 V VDS, -2 A ID, -55 to 150 degC, PG-SOT23, Reel, Green | Q1, Q2, Q3, Q4, Q5, Q6, Q7, Q8, Q9, Q10, Q11, Q12, Q13, Q14, Q15, Q16, Q17, Q18 | 18 Infineon | | BSS308PE | Volume Production | Digi-Key | BSS308PEH6327XTSA1CT-ND | 0.358 | 6.44
| NSV1C201MZ4T1G | Transistor | Q19 | 1
| Resistor | Resistor | R1, R2, R3, R4, R5, R6, R7, R8, R9, R10, R12, R13, R14, R15, R16, R17, R18, R19, R20, R26, R27, R28, R29, R30, R31, R32, R33, R34, R36, R37, R38, R39, R43, R44, R45, R47, R48, R50, R51, R52, R53, R54, R58, R59, R60, R61, R62, R63, R66, R67, R68, R69, R70, R71 | 54
| Resistor | Resistor | R11, R21, R22, R23, R24, R25, R35, R40, R41, R42, R46, R55, R56, R57, R64, R65, R72, R73 | 18
| Resistor | Resistor | R49, R74 | 2
| Resistor | Resistor | R75, R76, R77, R78, R79, R80, R81, R82, R83 | 9
| Resistor | Resistor | R84, R87, R88, R89, R90, R91 | 6
| Resistor | Resistor | R85 | 1
| Resistor | Resistor | R86 | 1
| Resistor | Resistor | R92 | 1
| Resistor | Resistor | R94, R95, R96, R97 | 4
| SM91502ALE | BMS XFORMER 1-CH 1000V AECQ +125 | T1, T2 | 2 | Bourns | SM91502ALE | Volume Production | Newark | 95AC3538 | 2.81 | 5.62
| LTC6813HLWE-1#3ZZPBF | 18 CHANNEL MULTICELL BATTERY STA | U1 | 1 | Analog Devices / Linear Technology | LTC6813HLWE-1#3ZZPBF
| PDZ7.5B,115 | Zener Diode | Z1, Z2, Z3, Z4, Z5, Z6, Z7, Z8, Z9, Z10, Z11, Z12, Z13, Z14, Z15, Z16, Z17, Z18 | 18

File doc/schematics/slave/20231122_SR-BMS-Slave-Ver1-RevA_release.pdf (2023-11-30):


r Populate jumperrespective to # of cel

e : 11/23/ 20 2 3 | Sheet of Spar tan Racing & SJSU
Fi l e : C : \U ser s \..\bm sSlave_mai n . S chDo c | D rawn By: Vincent Pham, Vincent S aw



Si z e | Num b er | Revi s i on

e : 11/23/ 20 2 3 | Sheet of
Fi l e : C : \U ser s \..\bm sSlave_cel l s . S chDo c | D rawn By: Vincent Pham, Vincent S aw


To upstream BMS slave (or master)

To downstream BMS slave

FOLLOW DATASHEET LAYOUT GUIDELINES!


Line # | Name | Description | Designator | Quantity | Manufacturer 1 | Manufacturer Part Number 1 | Manufacturer Lifecycle 1 | Supplier 1 | Supplier Part Number 1 | Supplier Unit Price 1 | Supplier Subtotal 1
| 885382207009 | Multilayer Ceramic Chip Capacitor WCAP-CSST Series 0805 10000pF X7R0805103K100DFC T1S000 | C0, C1, C2, C3, C4, C5, C6, C7, C8, C9, C10, C11, C12, C13, C14, C15, C16, C17, C18, C19, C20, C21, C22, C23, C25, C26, C27, C28, C29, C30, C31, C32, C33, C34, C35, C36, C53, C54, C55, C56 | 40
| Capacitor | Capacitor | C37, C38, C39, C40, C41, C42, C43, C44, C45, C46, C47 | 11
| Capacitor | Capacitor | C48, C49, C50, C51, C52 | 5
| MFU0603FF00500P500 | Fuse | F1, F2, F3, F4, F5, F6, F7, F8, F9, F10, F11, F12, F13, F14, F15, F16, F17, F18 | 18
| BLM18PG330SN1D | Ferrite Bead | FB1 | 1
| 15-91-2025 | CONN HEADER SMD R/A 2POS 2.54MM | J1, J2 | 2 | Molex | 15-91-2025 | Volume Production | Avnet | 0015912025 | 3.18 | 6.36
| 70553-0044 | Connector | J3 | 1
| 70555-0018 | Connector | J4 | 1
| LS_L29K-G1H2-1 | LED | LED1, LED2, LED3, LED4, LED5, LED6, LED7, LED8, LED9, LED10, LED11, LED12, LED13, LED14, LED15, LED16, LED17, LED18 | 18
| BSS308PE | P-Channel OptiMOS P3 Small-Signal-Transistor, -30 V VDS, -2 A ID, -55 to 150 degC, PG-SOT23, Reel, Green | Q1, Q2, Q3, Q4, Q5, Q6, Q7, Q8, Q9, Q10, Q11, Q12, Q13, Q14, Q15, Q16, Q17, Q18 | 18 | Infineon | BSS308PE | Volume Production | Mouser | 726-BSS308PEH6327XTS | 0.319 | 5.74
| NSV1C201MZ4T1G | Transistor | Q19 | 1
| Resistor | Resistor | R1, R2, R3, R4, R5, R6, R7, R8, R9, R10, R12, R13, R14, R15, R16, R17, R18, R19, R20, R26, R27, R28, R29, R30, R31, R32, R33, R34, R36, R37, R38, R39, R43, R44, R45, R47, R48, R50, R51, R52, R53, R54, R58, R59, R60, R61, R62, R63, R66, R67, R68, R69, R70, R71 | 54
| Resistor | Resistor | R11, R21, R22, R23, R24, R25, R35, R40, R41, R42, R46, R55, R56, R57, R64, R65, R72, R73 | 18
| Resistor | Resistor | R49, R74 | 2
| Resistor | Resistor | R75, R76, R77, R78, R79, R80, R81, R82, R83 | 9
| Resistor | Resistor | R84, R87, R88, R89, R90, R91 | 6
| Resistor | Resistor | R85 | 1
| Resistor | Resistor | R86 | 1
| Resistor | Resistor | R92 | 1
| Resistor | Resistor | R94, R95, R96, R97 | 4
| SM91502ALE | BMS XFORMER 1-CH 1000V AECQ +125 | T1, T2 | 2 | Bourns | SM91502ALE | Volume Production | Newark | 95AC3538 | 2.81 | 5.62
| LTC6813HLWE-1#3ZZPBF | 18 CHANNEL MULTICELL BATTERY STA | U1 | 1 | Analog Devices / Linear Technology | LTC6813HLWE-1#3ZZPBF
| PDZ7.5B,115 | Zener Diode | Z1, Z2, Z3, Z4, Z5, Z6, Z7, Z8, Z9, Z10, Z11, Z12, Z13, Z14, Z15, Z16, Z17, Z18 | 18

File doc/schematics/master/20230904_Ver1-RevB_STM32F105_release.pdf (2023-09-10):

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
## Title

Size | Number | Revision
A
Date: | 9/04/2023 | Sheet of
File: | C:\Users\..\bmsMaster_cover.SchDoc | Drawn By:

# Spartan Racing BMS Master Board

# B.S. Senior Project SP23-FA23 Vincent Saw, Vincent Pham, Josh Samoy, Abegail Palad Advisor: Preetpal Kang

# Version 1, Revision B (STM32F105)

# Designer: Vincent Saw

# Cover Sheet

## Spartan Racing & SJSU Vincent Saw

# Main Crystal Oscillator

GND | GND | TP


CL = ((CX1 x CX2) / (CX1 + CX2)) + Cstray
Crystal CL=18pF, assuming Cstray=4pF

Read power source state
PMUX_ST

RTC Crystal Oscillator
CL = ((CX1 x CX1) / (2 x CX1)) + Cstray
Crystal CL=12.5pF, assuming Cstray=2pF

Reset Circuit
Also resettable via USB

A A

1 2


A A

## P5V0_BAT P5V0_USB


To OR power supplies


Route to Busbar Mount Holes TP

Skipping AGND usage for this revision
Look into later?

WSBS5216L1000KK is 12W
Route to Busbar Mount Holes

A A

## P3V3_MAIN


UART test points ok because

A A
0


ISO_xA_P
To 2-pin connector for BMS slave


Requires external 5V and GND for isolation purposes
TODO: Add on-board isolated power for VCC2/GND2

f_corner = 250kHz if CAN 500kbps
C_split >= 1.6nF?
Multiply f_corner by factor of 5?

Using 100n for now, mega low pass, generous threshold

A A

# P3V3_MAIN 2 1


USB/UART0 Activity Indication LEDs 2 1

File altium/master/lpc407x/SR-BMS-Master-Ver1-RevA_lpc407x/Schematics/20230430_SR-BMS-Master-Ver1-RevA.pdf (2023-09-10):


Si z e | Num b er | Revi s i on

e : 4/30/ 20 2 3 | Sheet of Spar tan Racing & SJSU
Fi l e : C : \U ser s \..\bm s Mas ter_mai n . S chDo c | D rawn By: V incent Saw




7 | | 1 1


To 2-pin connector for BMS slave



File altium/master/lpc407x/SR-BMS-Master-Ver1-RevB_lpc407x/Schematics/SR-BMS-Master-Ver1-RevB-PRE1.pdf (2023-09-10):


MCU_VSS_4

ADC/DAC Analog Supply

ONLY POPULATE 0 OHMS IF ADC/DAC UNUSED

AND DEPOPULATE FERRITE BEADS/CAPIF ADC/DAC UNUSED

JTAG_TDI 2
JTAG_TMS_(SWDIO) 3 | MCU_VSS_3
JTAG_TRST 4 JTAG_TCK_(SWDCLK) 5

MCU_nRST MCU_RTCX2 | | RESET 14

MCU_VBAT | | VBAT 16

P1[30] 18
XTAL1 19 | | | MCU_VDD_2

X1 | TP8 TP 1 | MCU_XTAL2 | | XTAL2 20 | C5 | C6

Reset Circuit
Also resettable via USB

Size B | Number | Revision

Date: 5/04/2023 | Sheet of Spartan Racing & SJSU
File: C:\Users\..\bmsMaster_main.SchDoc | Drawn By: Vincent Saw



To OR power supplies


7 | | 1 1


To 2-pin connector for BMS slave


CA N_BM S_VCC_1 | 1 | 4

CA N_BM S_VCC_2 | 1 | 4


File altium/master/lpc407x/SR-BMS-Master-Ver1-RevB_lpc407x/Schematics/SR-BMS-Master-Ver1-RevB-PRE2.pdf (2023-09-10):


2 | | TP3
3 | M C U_VSS_ 3
4 5

Si z e | Num b er | Revi s i on

e : 5/05/ 20 2 3 | Sheet of Spar tan Racing & SJSU
Fi l e : C : \U ser s \..\bm s Mas ter_mai n . S chDo c | D rawn By: V incent Saw



To OR power supplies


7 | | 1 1


To 2-pin connector for BMS slave


CA N_BM S_VCC_1 | 1 | 4

CA N_BM S_VCC_2 | 1 | 4


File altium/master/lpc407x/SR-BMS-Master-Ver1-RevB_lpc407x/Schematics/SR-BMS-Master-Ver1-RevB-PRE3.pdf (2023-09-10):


2 | TP3
4 5

Si z e | Num b er | Revi s i on

e : 5/09/ 20 2 3 | Sheet of Spar tan Racing & SJSU
Fi l e : C : \U ser s \..\bm s Mas ter_mai n . S chDo c | D rawn By: V incent Saw




7 | | 1 1


To 2-pin connector for BMS slave




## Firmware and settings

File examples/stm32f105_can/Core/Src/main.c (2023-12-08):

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
/* Includes ------------------------------------------------------------------*/
#include "main.h"
#include "adc.h"
#include "can.h"
#include "spi.h"
#include "tim.h"
#include "usart.h"
#include "usb_device.h"
#include "gpio.h"

/* USER CODE BEGIN Includes */
#include "string.h"
#include "ltc6813.h"

/* USER CODE END Includes */

/* USER CODE BEGIN PD */
#define NUM_DEVICES_DEFAULT					2	//2 slave boards
#define NUM_SERIES_GROUPS_PER_MOD_DEFAULT	12	//12 in series
#define NUM_SERIES_GROUPS_TOTAL_DEFAULT		(NUM_DEVICES_DEFAULT * NUM_SERIES_GROUPS_PER_MOD_DEFAULT) //24 series groups

#define LTC_DELAY_MS			1000 //500ms update delay
#define LED_HEARTBEAT_DELAY_MS	500 //500ms update delay
#define CAN1_DELAY_MS			100 //100ms update delays

/* USER CODE END PD */


/* USER CODE BEGIN PV */

typedef struct _TimerPacket {
	uint32_t 		ts_prev;	//Previous timestamp
	uint32_t 		ts_curr; 	//Current timestamp
	uint32_t		delay;		//Amount to delay
} TimerPacket;

/* USER CODE END PV */

void SystemClock_Config(void);
/* USER CODE BEGIN PFP */

void TimerPacket_Init(TimerPacket *tp, uint32_t delay);

//Returns 1 at every tp->delay interval
uint8_t TimerPacket_FixedPulse(TimerPacket *tp);

//Set Heartbeat LED to LOW
void LED_Heartbeat_Init(void);

//Toggle Heartbeat LED
void LED_Heartbeat_Toggle(void);

/* USER CODE END PFP */

/**
  * @brief  The application entry point.
  * @retval int
  */
int main(void)
{
  /* USER CODE BEGIN 1 */
  TimerPacket tp_led_heartbeat;
  TimerPacket tp_ltc;
  TimerPacket tp_can1;

  uint16_t read_val[NUM_SERIES_GROUPS_TOTAL_DEFAULT]; //To hold all series groups' data

  /* USER CODE END 1 */

  /* MCU Configuration--------------------------------------------------------*/

  /* Reset of all peripherals, Initializes the Flash interface and the Systick. */
  HAL_Init();

  /* Configure the system clock */
  SystemClock_Config();

  /* Initialize all configured peripherals */
  MX_GPIO_Init();
  MX_ADC1_Init();
  MX_ADC2_Init();
  MX_CAN1_Init();
  MX_CAN2_Init();
  MX_TIM7_Init();
  MX_SPI1_Init();
  MX_USART2_UART_Init();
  MX_USART3_UART_Init();
  MX_USB_DEVICE_Init();
  /* USER CODE BEGIN 2 */

  //Start timer
  TimerPacket_Init(&tp_led_heartbeat, LED_HEARTBEAT_DELAY_MS);
  TimerPacket_Init(&tp_ltc, LTC_DELAY_MS);
  TimerPacket_Init(&tp_can1, CAN1_DELAY_MS);

  //Set Heartbeat LED initial value to LOW
  LED_Heartbeat_Init();

  //Pull SPI1 nCS HIGH (deselect)
  LTC_nCS_High();

  LTC_Set_Num_Devices(NUM_DEVICES_DEFAULT);
  LTC_Set_Num_Series_Groups(NUM_SERIES_GROUPS_PER_MOD_DEFAULT);

  uint8_t startErr = (uint8_t)CAN1_Start();

	uint32_t testTxMailbox;
	uint8_t msg[8];

	msg[0] = 0xde;
	msg[1] = 0xad;
	msg[2] = 0xbe;
	msg[3] = 0xef;

	CAN_TxHeaderTypeDef testTx;
	testTx.IDE = CAN_ID_STD;
	testTx.StdId = 0x123;
	testTx.RTR = CAN_RTR_DATA;
	testTx.DLC = 4;
  /* USER CODE END 2 */

  /* Infinite loop */
  /* USER CODE BEGIN WHILE */
  while (1)
  {
    /* USER CODE END WHILE */

    /* USER CODE BEGIN 3 */

	  	//LED HEARTBEAT
		if (TimerPacket_FixedPulse(&tp_led_heartbeat)) { LED_Heartbeat_Toggle(); }

		//CAN TX TEST
		if (TimerPacket_FixedPulse(&tp_can1)) {
			uint8_t err;
			char serial_buf[32];


			//if (CAN1_GetTxMailboxesFreeLevel()) {
				err = (uint8_t)CAN1_Tx(&testTx, msg, &testTxMailbox);

				sprintf(serial_buf, "0x%X 0x%X 0x%lX\n", startErr, err, CAN1_CheckError());

				USB_Transmit(serial_buf, strlen(serial_buf));
			//}
		}

		//READ CELL VOLTAGE
		if (TimerPacket_FixedPulse(&tp_ltc)) {
			/*
			char buf[20];
			char out_buf[1024] = "";
			char char_to_str[2];

			LTC_ReadRawCellVoltages((uint16_t *)read_val);

			char_to_str[0] = '\n';
			char_to_str[1] = '\0';

			for (uint8_t i = 0; i < NUM_SERIES_GROUPS_TOTAL_DEFAULT; i++) {
				sprintf(buf, "C%u:%u/1000 V", i+1, read_val[i]);
				strncat(out_buf, buf, 20);
				strncat(out_buf, char_to_str, 3);
			}
			strncat(out_buf, char_to_str, 3);

			USB_Transmit(out_buf, strlen(out_buf));
			*/
		}
  }
  /* USER CODE END 3 */
}

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
/* USER CODE BEGIN 4 */

//Initialize struct values
void TimerPacket_Init(TimerPacket *tp, uint32_t delay)
{
	tp->ts_prev 	= 0;		//Init to 0
	tp->ts_curr 	= 0; 		//Init to 0
	tp->delay		= delay;	//Init to user value
}

//tp->delay = update after X ms
uint8_t TimerPacket_FixedPulse(TimerPacket *tp)
{
	tp->ts_curr = HAL_GetTick(); //Record current timestamp

	if (tp->ts_curr - tp->ts_prev > tp->delay) {
		tp->ts_prev = tp->ts_curr; //Update prev timestamp to current
		return 1; //Enact event (time interval is a go)
	}
	return 0; //Do not enact event
}

void LED_Heartbeat_Init(void) {
	HAL_GPIO_WritePin(MCU_HEARTBEAT_LED_GPIO_Port, MCU_HEARTBEAT_LED_Pin, GPIO_PIN_RESET); //Set GPIO LOW
}

void LED_Heartbeat_Toggle(void) {
	HAL_GPIO_TogglePin(MCU_HEARTBEAT_LED_GPIO_Port, MCU_HEARTBEAT_LED_Pin); //Set GPIO LOW
}

/* USER CODE END 4 */
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


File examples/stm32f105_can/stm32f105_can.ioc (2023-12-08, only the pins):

Mcu.UserName=STM32F105RBTx
PA0-WKUP.GPIO_Label=MCU_USB_INT
PA0-WKUP.Signal=SYS_WKUP
PA11.Signal=USB_OTG_FS_DM
PA12.Signal=USB_OTG_FS_DP
PA13.Signal=SYS_JTMS-SWDIO
PA14.Signal=SYS_JTCK-SWCLK
PA2.Signal=USART2_TX
PA3.Signal=USART2_RX
PA4.GPIO_Label=LTC_nCS
PA4.Signal=GPIO_Output
PA5.Signal=SPI1_SCK
PA6.Signal=SPI1_MISO
PA7.Signal=SPI1_MOSI
PA9.Signal=USB_OTG_FS_VBUS
PB10.Signal=USART3_TX
PB11.Signal=USART3_RX
PB12.Signal=CAN2_RX
PB13.Signal=CAN2_TX
PB8.Signal=CAN1_RX
PB9.Signal=CAN1_TX
PC0.Signal=ADCx_IN10
PC1.Signal=ADCx_IN11
PC14-OSC32_IN.Signal=RCC_OSC32_IN
PC15-OSC32_OUT.Signal=RCC_OSC32_OUT
PC2.Signal=ADCx_IN12
PC3.Signal=ADCx_IN13
PC4.Signal=ADCx_IN14
PC5.Signal=ADCx_IN15
PC6.GPIO_Label=MCU_HEARTBEAT_LED
PC6.Signal=GPIO_Output
PC8.GPIO_Label=PMUX_ST
PC8.Signal=GPIO_Input
PD0-OSC_IN.Signal=RCC_OSC_IN
PD1-OSC_OUT.Signal=RCC_OSC_OUT

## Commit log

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2023-04-26 Initial commit of master and slave board schematic
    [SR-BMS.PrjPcb, bmsMaster_main.SchDoc, bmsSlave_main.SchDoc]
2023-04-26 Removed slave sch from master PCB project
    [bmsSlave_main.SchDoc]
2023-04-26 Renamed SR-BMS to SR-BMS-Master
    [SR-BMS.PrjPcb]
2023-04-26 Created new SR-BMS-Slave Altium project
    [SR-BMS-Slave.PrjPcb, bmsMaster_main.SchDoc, bmsSlave_main.SchDoc]
2023-04-26 Added SamacSys to project library
    [SR-BMS-Master.PrjPcb]
2023-04-29 Completed MCU power pin interfacing
    [bmsMaster_main.SchDoc, bmsMaster_usb.SchDoc]
2023-04-29 Rearranged ADC/DAC MCU power arrangement reflective of RDB4078 schematic
    [bmsMaster_main.SchDoc]
2023-04-29 Added XTAL template to MCU
    [bmsMaster_main.SchDoc]
2023-04-29 Added 10-pin JTAG interface proportional to J-Link pinout
    [bmsMaster_main.SchDoc]
2023-04-29 Removed inductor/ferrite bead values temporarily
    [bmsMaster_main.SchDoc]
2023-04-29 Moved 10-pin JTAG to connector schematic
    [bmsMaster_conn.SchDoc, bmsMaster_main.SchDoc]
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2023-04-30 First version of isoSPI interface
    [SR-BMS-Master.PrjPcb, bmsMaster_conn.SchDoc, bmsMaster_isospi.SchDoc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]
2023-04-30 Renamed JTAG nets to more align with naming convention
    [bmsMaster_conn.SchDoc, bmsMaster_main.SchDoc]
2023-04-30 Added SnapEDA files and also 4-pin connector
    [171977-0004.PcbLib, 171977-0004.SchLib, SR-BMS-Master.PrjPcb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]
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2023-04-30 Moved ADC/DAC power supply circuit to top left of schematic, assigned nets to VDDA, VREFP, VSSA
    [bmsMaster_main.SchDoc]
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2023-04-30 Added reset circuit
    [bmsMaster_main.SchDoc]
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2023-04-30 Added off-board connectors for UART/serial 2 and 3
    [bmsMaster_conn.SchDoc]
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2023-04-30 Moved SPI0 pin set to different pins, renamed CSn to nCS to reflect naming convention standard
    [bmsMaster_isospi.SchDoc, bmsMaster_main.SchDoc]
2023-04-30 Moved UART2 pin set to different pins to make room for CAN
    [bmsMaster_main.SchDoc]
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2023-04-30 Added No ERC directives to remaining MCU GPIO
    [bmsMaster_main.SchDoc]
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2023-05-04 Initial Ver1 RevB commit and testpoint library commit
    [171977-0004.PcbLib, 171977-0004.SchLib, SR-BMS-Master-Ver1-RevB.PrjPcb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]
2023-05-04 Added common mode noise low-pass (choke) to CAN Xceiver CANH/CANL
    [bmsMaster_can.SchDoc]
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2023-05-05 Added footprints to most generic capacitors and all generic resistors
    [bmsMaster_can.SchDoc, bmsMaster_isospi.SchDoc, bmsMaster_led.SchDoc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]
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2023-05-05 Added series jumpers to oscillator circuits
    [bmsMaster_main.SchDoc]
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2023-05-05 Added missing footprint to reset button
    [bmsMaster_main.SchDoc]
2023-05-05 Swapped LM3940 cap with low-ESR cap with footprint as well
    [bmsMaster_power.SchDoc]
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2023-05-06 Swapped CANH/CANL connector positions
    [bmsMaster_conn.SchDoc]
2023-05-06 Swapped isoSPI MA/PA connector positions
    [bmsMaster_conn.SchDoc]
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2023-05-06 Added MCU testpoints and set all designator text to 40mil height
    [bmsMaster.PcbDoc]
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2023-05-06 Pre-routing state of project. Also redid board resizing.
    [bmsMaster.PcbDoc, bmsMaster_can.SchDoc, bmsMaster_conn.SchDoc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]
2023-05-06 Added SR logo, version, and credits to silkscreen
    [bmsMaster.PcbDoc]
2023-05-06 Adjusted existing aux text to be on top layer and 25mil height
    [bmsMaster.PcbDoc]
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2023-05-06 Fixed silk to silk violations
    [bmsMaster.PcbDoc]
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2023-05-06 Routed JTAG connector and a few loose GPIO
    [bmsMaster.PcbDoc]
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2023-05-09 Changed all vias to Thru away from Blind to align with JLCPCB requirements
    [bmsMaster.PcbDoc]
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2023-05-09 Changed SMD Pad to Track clearance from 5mil to 8mil, and reduced diff pair trace width from 15mil to 10mil to align with JLCPCB requirements
    [bmsMaster.PcbDoc]
2023-05-09 Rerouted LDO circuit, placed capacitors closer to LDO pins
    [bmsMaster.PcbDoc]
2023-05-09 Rerouted isoSPI diff pair to align with layout guidelines of no trace crossing
    [bmsMaster.PcbDoc]
2023-05-09 Changed dielectric thickness to match ISO1050 recommended layer stack
    [bmsMaster.PcbDoc]
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2023-05-10 Changed LDO and USB thermal pads to be thermally relieved direct connect
    [bmsMaster.PcbDoc]
2023-05-10 Removed power traces, replaced with polygon planes
    [bmsMaster.PcbDoc]
2023-05-10 Changed small vias to 25mil dia, 14mil hole
    [bmsMaster.PcbDoc]
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2023-05-10 Added copper heatsink on top signal layer for LDO heat dissipation, as suggested by Patrick and Jose
    [bmsMaster.PcbDoc]
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2023-05-10 Moved XTALs closer to MCU, added power vias for right side MCU power pins:
    [bmsMaster.PcbDoc]
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2023-05-10 Create SR-BMS-Slave.SchDoc
    Single Device 2-Wire port A using LTC6813
    [SR-BMS-Slave.SchDoc]
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2023-07-16 Moved existing LPC4078 design into its own folder
    [171977-0004.PcbLib, 171977-0004.SchLib, SR-BMS-Master-Ver1-RevA_lpc407x.PrjPcb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]
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2023-09-05 Added Sep 9 2023 board files - already released to JLCPCB
    [SR-BMS-Master-Ver1-RevB_stm32f105.PrjPcb, bmsMaster_can.SchDoc, bmsMaster_conn.SchDoc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]
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2023-09-13 Replaced cell netnames with wires
    [bmsSlave_main.SchDoc]
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2023-09-19 Moved user code to user code sections to prevent CubeMX overwrite
    [main.c]
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2023-09-27 Swapped endianness on RDCVA command
    [ltc6813.c]
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2023-09-28 Corrected uint16_t memcpy indexing so that multi-slave should work, and added device selection quantity
    [ltc6813.c, main.c]
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2023-10-06 Minor Net Label fixes
    [bmsSlave_main.SchDoc]
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2023-10-08 Replaced thermistor connector witto 10-pos 2.54mm size
    [bmsSlave_main.SchDoc]
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2023-10-23 Added fusing to cell sheet as well as some visual edits
    [SR-BMS-Slave-Ver1-RevA.PrjPcb, bmsSlave_cells.SchDoc]
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2023-10-24 Fixed shorted nets on capacitors and balancing control
    [bmsSlave_cells.SchDoc]
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2023-10-27 Update bmsSlave_conn.SchDoc
    Removed 'Cell0' Net-Label from J4B and moved Net-Labels up.
    Added ground to pin20
    [bmsSlave_conn.SchDoc]
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2023-10-27 Updated Footprint path for some components
    Will cause error when sourcing components - need to branch
    [SR-BMS-Slave-Ver1-RevA.PrjPcb, bmsSlave.PcbDoc, bmsSlave_cells.SchDoc]
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2023-11-03 Added dependencies folder
    Contains SchLib, PcbLib, and footprints
    [885382207009.SchLib, 885382207009.stp, BLM15PX600BH1D.SchLib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]
2023-11-07 bmsSlave_cells and bmsSlave_conn PCB Layout
    Updated designators to match Layout sequence
    Cells and connectors partial layout
    [bmsSlave.PcbDoc, bmsSlave_cells.SchDoc]
2023-11-07 Layout for bmsSlave Cells, Updated bmsSlave_cells
    Connected Cell1_F to net C0
    [SR-BMS-Slave-Ver1-RevA.PrjPcb, bmsSlave.PcbDoc, bmsSlave_cells.SchDoc]
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2023-11-10 Update bmsSlave_cells.SchDoc
    Missed C33 and C16 intersection
    [bmsSlave_cells.SchDoc]
2023-11-10 Update bmsSlave_cells.SchDoc
    Missed C34 & C30 intersection
    [bmsSlave_cells.SchDoc]
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2023-11-15 Update bmsSlave.PcbDoc
    complete version but missing
    [bmsSlave.PcbDoc]
2023-11-15 Updated missing connections
    [bmsSlave.PcbDoc, bmsSlave_conn.SchDoc]
2023-11-15 Update bmsSlave.PcbDoc
    Missing connections
    [bmsSlave.PcbDoc]
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2023-11-20 Update bmsSlave.PcbDoc
    Routed standard components + routed grounds
    [bmsSlave.PcbDoc]
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2023-12-03 Fixed cell voltage division value on serial printout
    [main.c]
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2023-12-08 Added final senior project Altium outputs including proper schematic labeling and colored print-ready schematics
    [SR-BMS-Master-Ver1-RevB_stm32f105.PrjPcb, SR-BMS-Slave-Ver1-RevA.PrjPcb, bmsMaster_can.SchDoc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]
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

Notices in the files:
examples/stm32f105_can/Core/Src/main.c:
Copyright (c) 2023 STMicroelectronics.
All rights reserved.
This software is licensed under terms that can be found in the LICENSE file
